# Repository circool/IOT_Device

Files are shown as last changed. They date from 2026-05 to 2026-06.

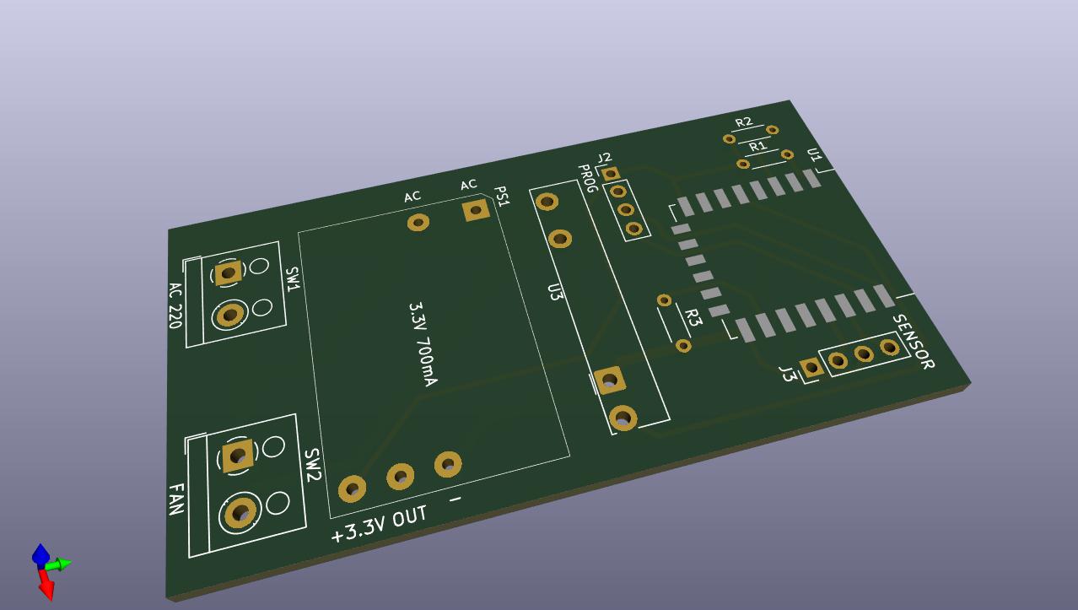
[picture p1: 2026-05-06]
Fan/Fan.jpg

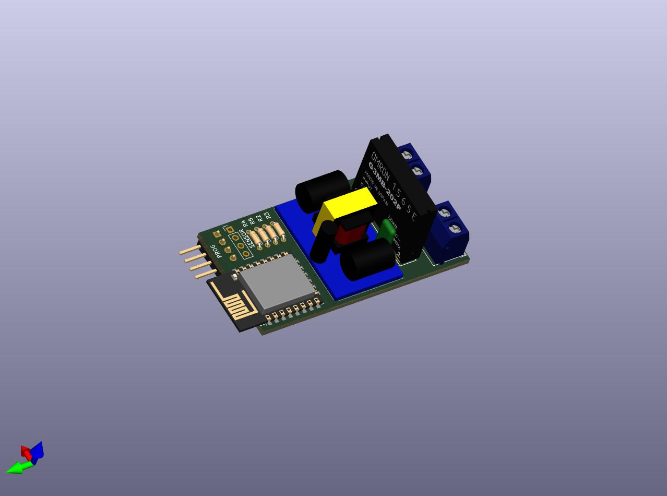
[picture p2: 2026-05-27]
Fan/Fan-review.jpg

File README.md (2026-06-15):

# Universal Smart Home Device







Универсальное устройство для умного дома с поддержкой датчиков температуры/влажности, ШИМ-управления вентилятором, MQTT и веб-интерфейсом. Идеально подходит для автоматизации вытяжной вентиляции в ванной и туалете.

## Особенности

- **Три типа устройств** в одной прошивке:
  - Вентилятор с датчиками (автоматическое управление)
  - Автономный датчик температуры/влажности
  - Управляемый выключатель

- **Smart-управление**:
  - Автоматическое включение по температуре/влажности
  - Ручное управление через MQTT и Web
  - Таймер отложенного включения
  - Аварийное отключение по таймеру

- **Тихий режим (ШИМ)**:
  - Регулировка скорости 0-100%
  - **Адаптивный режим** — автоматическая подстройка мощности
  - Стартовый импульс для надёжного запуска

- **Поддержка платформ**:
  - ESP8266 (NodeMCU, ESP-12F)
  - ESP32 (любые версии)

- **Датчики**:
  - AHT10 (I2C)
  - DHT11/DHT22 (1-Wire)

- **Связь и управление**:
  - MQTT с LWT и autodiscovery-ready топиками
  - Веб-интерфейс для настройки
  - OTA обновления прошивки
  - Точка доступа (AP) для первоначальной настройки
  - Сброс настроек кнопкой / MQTT / Web

- **Надёжность**:
  - Хранение настроек в EEPROM с CRC16
  - Watchdog Timer (WDT)
  - Автоматическое восстановление после потери связи

## Содержание

- [Поддерживаемые устройства](#-поддерживаемые-устройства)
- [Аппаратные требования](#-аппаратные-требования)
- [Схема подключения](#-схема-подключения)
- [Установка прошивки](#-установка-прошивки)
- [Конфигурация](#-конфигурация)
  - [Настройки в коде (config.h)](#-настройки-в-коде-configh)
  - [Настройки в среде (platformio.ini)](#-настройки-в-среде-platformioini)
  - [Файл credentials.h (опционально)](#-файл-credentialsh-опционально)
- [MQTT топики](#-mqtt-топики)
- [Логика работы](#-логика-работы)
- [Компиляция из исходников](#-компиляция-из-исходников)
- [TODO](#-todo)

## Поддерживаемые устройства

| Тип | DEVICE_TYPE | Компоненты | Применение |
|-----|---|---|---|
| **Вентилятор** | 1 | Датчик + ШИМ + реле | Вытяжка в ванной/туалете |
| **Датчик** | 2 | Только датчик | Мониторинг микроклимата |
| **Выключатель** | 3 | Реле (без датчика) | Управление освещением/нагрузкой |

## Аппаратные требования

### Компоненты (максимальная конфигурация)

| Компонент | Модель | Примечание |
|---|---|---|
| Микроконтроллер | ESP8266 (NodeMCU) или ESP32 | Любая плата с WiFi |
| Датчик (опционально) | AHT10 или DHT11/DHT22 | I2C или 1-Wire |
| Исполнительное реле | Твердотельное реле G3MB-202P | Для реализации ШИМ |
| Питание | AC-DC 220V → 3.3V | Подключается параллельно освещению |
| Кнопка сброса | Тактовая на замыкание | GPIO0 → GND |
| Светодиод индикации | Любой | С резистором 220-470 Ом (GPIO2* → GND, инверсия) |

### Назначение пинов

| Функция | ESP8266 | ESP32 |
|---|---|---|
| Управление (PWM) | GPIO14 | GPIO4 |
| AHT10 SDA | GPIO4 | GPIO21 |
| AHT10 SCL | GPIO5 | GPIO22 |
| DHT11/22 | GPIO4* | GPIO16* | Однопроводной датчик (GPIO → DATA) |
| Кнопка сброса | GPIO0 | GPIO0 |
| Светодиод индикации связи | GPIO2** | GPIO2** |

**Важно:** Для работы ШИМ-регулировки обязательно используйте **твердотельное реле (SSR)**, а не механическое!

**\*** DHT11/22 можно подключать к любым свободным пинам, кроме GPIO0, GPIO2, GPIO15 (ESP8266) из-за особого поведения при загрузке. Рекомендуемые пины: GPIO4, GPIO5, GPIO16 (ESP8266) или GPIO16, GPIO17, GPIO18 (ESP32).

**\*\*** На многих модулях NodeMCU и ESP32-devkit на GPIO2 уже установлен встроенный синий светодиод. При использовании DHT на GPIO2 возникнет конфликт — выберите другой пин для датчика или отключите LED.

## Схема подключения

```
220V AC →→→ AC-DC 3.3V →→→ ESP
           ↓
         Свет
           
220V AC →→→ SSR (реле) →→→ Вентилятор
           ↑
        GPIO (PWM)
           
ESP →→→ I2C →→→ AHT10 (SDA/SCL)
```

**Принцип работы:**
1. Свет включён → устройство получает питание
2. Устройство решает: включать вентилятор или нет (по датчикам)
3. Если нужно — подаёт ШИМ-сигнал на реле
4. Свет выключен → устройство обесточено → вентилятор выключен

## Установка прошивки

### Способ 1: PlatformIO (рекомендуется)

```bash
# Клонировать репозиторий
git clone https://github.com/circool/IOT_Device.git
cd IOT_Device

# Собрать для ESP8266
pio run -e esp8266 -t upload

# Или для ESP32
pio run -e esp32 -t upload
```

### Способ 2: Arduino IDE

1. Установите поддержку ESP8266/ESP32 через Boards Manager
2. Установите библиотеки:
   - PubSubClient by Nick O'Leary
   - Adafruit AHTX0
   - DHT sensor library
   - ElegantOTA
3. Откройте `main.cpp`, выберите плату и загрузите

### Первоначальная настройка

1. **Первый запуск** — устройство создаст точку доступа `Fan_XXXX` (или `Sensor_XXXX`/`Switch_XXXX`)
2. **Подключитесь** к этой WiFi сети (пароль отсутствует)
3. **Откройте браузер** по адресу `http://192.168.4.1`
4. **Заполните настройки:**
   - WiFi SSID и пароль
   - MQTT брокер (адрес и порт)
   - Параметры управления (при необходимости)
5. **Сохраните** — устройство перезагрузится и подключится к вашей сети

## Конфигурация

### Настройки в коде (config.h)

```cpp
// Тип устройства
#define DEVICE_TYPE 1  // 1=Fan, 2=Sensor, 3=Switch

// Датчик (для TYPE 1,2)
#define SENSOR_TYPE 1  // 1=AHT10, 2=DHT

// Аппаратные пины
#define SWITCH_PIN 4     // Пин управления (ESP32)
#define STATUS_LED_PIN 2 // LED индикации (0 = отключён)
#define RESET_PIN 0      // Кнопка сброса

// Функционал
#define WIFI_ENABLED 1
#define MQTT_ENABLED 1
#define WEB_STATUS_ENABLED 1
#define OTA_ENABLED 1
#define WDT_ENABLED 1

// Тайминги
#define WDT_TIMER_MS 5000           // Watchdog таймер
#define AP_FALLBACK_TIMEOUT_MS 12000 // Таймаут до перехода в AP

// ШИМ параметры (для TYPE 1)
#define PWM_FREQUENCY 5      // Частота ШИМ (Гц)
#define PWM_RESOLUTION 8     // Разрешение (бит)
#define PWM_STARTING 200     // Стартовый импульс (мс)
#define DEFAULT_SPEED_PERCENT 50 // Скорость по умолчанию (%)

// Адаптивный режим
#define ADAPTIVE_EPSILON_TEMP 0.5   // Чувствительность температуры
#define ADAPTIVE_EPSILON_HUM 2.0    // Чувствительность влажности
#define ADAPTIVE_STEP_SIZE 10       // Шаг адаптации (%)
#define MIN_SPEED_PERCENT 10        // Минимальная скорость при адаптации

// Пороги по умолчанию (для TYPE 1)
#define DEFAULT_LOW_TEMP 27.0
#define DEFAULT_HIGH_TEMP 29.0
#define DEFAULT_LOW_HUM 55.0
#define DEFAULT_HIGH_HUM 60.0
```

### Настройки в среде (platformio.ini)

Файл `platformio.ini` содержит все параметры сборки для разных платформ. Раздел разделён на общие настройки (`[common]`) и специфичные для каждой платформы (`[env:esp32]`, `[env:esp8266]`).

#### Структура файла

```ini
[common]                           # Общие настройки для всех платформ
framework = arduino                # Фреймворк
monitor_speed = 115200             # Скорость Serial порта
upload_speed = 460800              # Скорость загрузки прошивки
build_flags =                      # Флаги компиляции (общие)
    -DMAGIC_VALUE=0x5A6B          # Магическое число для EEPROM
    -DDEVICE_TYPE=1               # Тип устройства (1=Fan, 2=Sensor, 3=Switch)
    -DVERSION=\"1.4\"             # Версия прошивки
    -DSTATUS_LED_PIN=2            # Пин статусного LED (0=отключён)

[env:esp32]                        # Сборка для ESP32
platform = espressif32             # Платформа
board = esp32dev                   # Тип платы
extends = common                   # Наследование общих настроек
lib_deps = ...                     # Зависимости (библиотеки)
build_flags =                      # Специфичные флаги для ESP32
    ${common.build_flags}         # Включить общие флаги
    -DSWITCH_PIN=4                # Пин управления для ESP32
    -DLED_INVERTED=0              # Инверсия LED (0=нормальная логика)

[env:esp8266]                      # Сборка для ESP8266
platform = espressif8266           # Платформа
board = nodemcu                    # Тип платы
extends = common                   # Наследование общих настроек
build_flags = 
    ${common.build_flags}
    -DSWITCH_PIN=14               # Пин управления для ESP8266
    -DLED_INVERTED=1              # Инверсия LED (1=инвертированная)
board_build.flash_size = 4MB      # Размер flash памяти
board_build.flash_mode = dout     # Режим flash (для ESP8266)
```

#### Основные параметры сборки

| Параметр | Значение | Описание |
|---|---|---|
| `-DMAGIC_VALUE` | `0x5A6B` | Идентификатор корректной конфигурации в EEPROM |
| `-DDEVICE_TYPE` | `1`, `2`, `3` | Тип устройства (см. таблицу ниже) |
| `-DVERSION` | `"1.4"` | Версия прошивки (отображается в веб-интерфейсе) |
| `-DSTATUS_LED_PIN` | `2` | Пин для LED индикации (`0` = отключить) |
| `-DSWITCH_PIN` | `4` (ESP32) / `14` (ESP8266) | Пин управления реле/вентилятором |
| `-DLED_INVERTED` | `0` или `1` | Инверсия логики LED (`1` = HIGH выключает) |

#### Типы устройств (DEVICE_TYPE)

```ini
# Вентилятор с датчиками (полная функциональность)
-DDEVICE_TYPE=1

# Только датчик (без управления нагрузкой)
-DDEVICE_TYPE=2

# Управляемый выключатель (без датчика)
-DDEVICE_TYPE=3
```

#### Включение/отключение функционала

```ini
# Основные модули (по умолчанию ВСЕ включены)
-DWIFI_ENABLED=1          # WiFi поддержка
-DMQTT_ENABLED=1          # MQTT клиент
-DWEB_STATUS_ENABLED=1           # Веб-сервер
-DOTA_ENABLED=1           # OTA обновления
-DWDT_ENABLED=1           # Watchdog Timer

# Отключение ненужного функционала (экономия памяти)
; -DMQTT_ENABLED=0        # Пример отключения MQTT
; -DWIFI_ENABLED=0        # Полностью отключить WiFi
; -DWDT_ENABLED=0         # Отключить Watchdog (только для отладки)
```

#### Настройка отладки (логирование)

```ini
# Глобальное включение отладки
-DLOG_LEVEL=4

```

**Пример включения полной отладки:**
```ini
build_flags =
    ${common.build_flags}
    -DLOG_LEVEL=4
    
```

#### Настройка MQTT функционала

```ini
# MQTT возможности (требуют MQTT_ENABLED=1)
-DMQTT_RESET_ENABLED=1            # Разрешить сброс через MQTT
-DMQTT_PUBLISH_RSSI=1             # Публиковать RSSI WiFi
-DMQTT_PUBLISH_RESET_REASON=1     # Публиковать причину перезагрузки
-DMQTT_IGNORE_PUBLISH_NORMAL_RESET_REASONS=1  # Не публиковать штатные перезагрузки

# Настройки MQTT соединения
-DMQTT_RECONNECT_DELAY_MS=5000    # Задержка переподключения (мс)
-DMQTT_KEEPALIVE_SEC=3            # Keepalive интервал (сек)
```

#### Настройка веб-интерфейса

```ini
# WEB возможности (требуют WEB_STATUS_ENABLED=1)
-DWEB_STATUS_ENABLED=1            # Страница статуса
-DWEB_SHOW_RSSI=1                 # Отображать RSSI на странице
-DWEB_RESET_ENABLED=1             # Кнопка сброса в веб-интерфейсе

# Настройки точки доступа (AP)
-DAP_ENABLED=1                    # Включить режим AP
-DAP_FALLBACK_TIMEOUT_MS=12000    # Таймаут до перехода в AP (мс)
-DAP_IP_ADDRESS="192.168.4.1"     # IP адрес в режиме AP
```

#### Настройки Watchdog (WDT)

```ini
# Параметры Watchdog (требуют WDT_ENABLED=1)
-DWDT_TIMER_MS=5000               # Таймаут WDT (мс)
-DLOOP_WATCHDOG_MULTIPLIER=3      # Множитель для основного цикла
```

#### Настройки датчиков

```ini
# Тип датчика (для DEVICE_TYPE=1 или 2)
-DSENSOR_TYPE=1                   # 1 = AHT10 (I2C), 2 = DHT11/22 (GPIO)

# Параметры для DHT (если SENSOR_TYPE=2)
-DSENSOR_PIN=2                    # GPIO пин для DHT
-DDHT_TYPE=DHT11                  # Тип DHT (DHT11, DHT22, DHT21)

# Интервал опроса датчика (сек)
-DSENSOR_DURATION=10
```

#### Настройки ШИМ (для вентилятора)

```ini
# ШИМ параметры (для DEVICE_TYPE=1)
-DPWM_ENABLED=1                   # Включить ШИМ
-DPWM_FREQUENCY=5                 # Частота ШИМ (Гц) — 5 Гц оптимально для SSR
-DPWM_RESOLUTION=8                # Разрешение ШИМ (бит) — 8 бит = 0-255
-DPWM_STARTING=200                # Длительность стартового импульса (мс)

# Адаптивный режим (требует PWM_ENABLED=1)
-DAPAPTIVE_ENABLED=1              # Включить адаптивный режим
-DDEFAULT_SPEED_PERCENT=50        # Скорость по умолчанию (%)
-DMIN_SPEED_PERCENT=10            # Минимальная скорость при адаптации
-DADAPTIVE_EPSILON_TEMP=0.5       # Чувствительность температуры (°C)
-DADAPTIVE_EPSILON_HUM=2.0        # Чувствительность влажности (%)
-DADAPTIVE_STEP_SIZE=10           # Шаг изменения скорости (%)
-DADAPTIVE_SPEED_SENSITIVITY=0.7  # Чувствительность к скорости изменения
```

#### Настройки аварийной защиты

```ini
# Таймеры безопасности (для DEVICE_TYPE=1 или 3)
-DEMERGENCY_ENABLED=1             # Включить аварийное отключение
-DMAX_ON_TIME_SEC=3600            # Максимальное время работы (сек) — 1 час

# Таймер отложенного включения
-DDEFAULT_DELAY_SECONDS=60        # Задержка по умолчанию (сек)
-DBOOT_SWITCH_STATE=0             # Состояние при старте (0=выкл, 1=вкл)
```

#### Настройки WiFi

```ini
# Параметры WiFi (требуют WIFI_ENABLED=1)
-DWIFI_CONNECT_TIMEOUT_MS=30000   # Таймаут подключения (мс)

# Включить сканирование сетей при старте (только для отладки)
; -DSCANING_WIFI_ENABLED=1
```

#### Примеры готовых конфигураций

**1. Минимальная конфигурация (только датчик, без WiFi):**
```ini
[env:esp32]
build_flags =
    -DDEVICE_TYPE=2
    -DWIFI_ENABLED=0
    -DMQTT_ENABLED=0
    -DWEB_STATUS_ENABLED=0
    -DSENSOR_TYPE=1
    -DSTATUS_LED_PIN=0
```

**2. Полная конфигурация с отладкой:**
```ini
[env:esp32]
build_flags =
    ${common.build_flags}
    -DLOG_LEVEL=4
    
```

**3. Выключатель с таймером (без датчика):**
```ini
[env:esp8266]
build_flags =
    ${common.build_flags}
    -DDEVICE_TYPE=3
    -DSWITCH_PIN=14
    -DDEFAULT_DELAY_SECONDS=30
    -DMAX_ON_TIME_SEC=1800
    -DBOOT_SWITCH_STATE=0
```

**4. Тихий режим с адаптацией:**
```ini
[env:esp32]
build_flags =
    ${common.build_flags}
    -DDEVICE_TYPE=1
    -DPWM_ENABLED=1
    -DAPAPTIVE_ENABLED=1
    -DPWM_FREQUENCY=5
    -DDEFAULT_SPEED_PERCENT=70
    -DMIN_SPEED_PERCENT=20
    -DADAPTIVE_STEP_SIZE=5
```

#### Важные замечания

1. **Приоритет флагов:** Специфичные для платформы флаги переопределяют общие
2. **Экономия памяти:** Отключайте ненужный функционал (`MQTT_ENABLED=0`, `WEB_STATUS_ENABLED=0`) для ESP8266 (особенно важно при ограниченной flash)
3. **Частота ШИМ:** Для твердотельных реле оптимальна 5-10 Гц. Более высокая частота может вызвать перегрев реле
4. **ESP8266 нюансы:**
   - Требуется `-Wno-sign-compare` и `-Wno-uninitialized` для подавления предупреждений
   - Режим flash `dout` обязателен для некоторых плат
   - LED часто инвертирован (`LED_INVERTED=1`)

#### Изменение параметров без перекомпиляции

Некоторые параметры можно изменить через веб-интерфейс или MQTT без перепрошивки:
- Пороги температуры/влажности
- Скорость вентилятора
- Таймеры (задержка, аварийное отключение)
- Режимы работы (ручной/автоматический)

Параметры, требующие перекомпиляции:
- Тип устройства (`DEVICE_TYPE`)
- Назначение пинов (`SWITCH_PIN`, `STATUS_LED_PIN`)
- Частота ШИМ (`PWM_FREQUENCY`)
- Включение/отключение модулей (`MQTT_ENABLED`, `WEB_STATUS_ENABLED`)
```

### Файл credentials.h (опционально)

Создайте этот файл для заводских настроек:

```cpp
// credentials.h
#define SSID_NAME "MyWiFi"
#define WIFI_PASSWORD "MyPassword"
#define MQTT_ADDRESS "192.168.1.100"
#define MQTT_PORT 1883
#define MQTT_USER "user"
#define MQTT_PASSWORD "pass"
```

## MQTT топики

Устройство использует префикс вида `{Type}_{ID}` (например `Fan_D84C`).

### Общие топики

| Топик | Направление | Формат | Описание |
|---|---|---|---|
| `{prefix}/status` | Dev → Broker | `Online`/`Offline` | Статус (LWT) |
| `{prefix}/version` | Dev → Broker | `1.4` | Версия прошивки |
| `{prefix}/c/system/reset` | Broker → Dev | `1` | Сброс настроек |

### Для вентилятора (TYPE 1)

| Топик | Направление | Описание |
|---|---|---|
| `{prefix}/fan/state` | Dev → Broker | `ON`/`OFF` |
| `{prefix}/c/fan/state` | Broker → Dev | Управление |
| `{prefix}/fan/speed` | Dev → Broker | Скорость (0-100%) |
| `{prefix}/c/fan/speed` | Broker → Dev | Установка скорости |
| `{prefix}/fan/adaptiveMode` | Dev → Broker | Адаптивный режим |
| `{prefix}/fan/delaySec` | Dev → Broker | Задержка включения |
| `{prefix}/fan/maxOnTime` | Dev → Broker | Аварийное отключение |
| `{prefix}/fan/sensorControlMode` | Dev → Broker | Режим датчика |
| `{prefix}/sensor/temperature` | Dev → Broker | Температура |
| `{prefix}/sensor/humidity` | Dev → Broker | Влажность |
| `{prefix}/sensor/lowTemp` | Dev → Broker | Нижний порог T |
| `{prefix}/c/sensor/highTemp` | Broker → Dev | Верхний порог T |

### Для датчика (TYPE 2)

| Топик | Направление | Описание |
|---|---|---|
| `{prefix}/sensor/temperature` | Dev → Broker | Температура |
| `{prefix}/sensor/humidity` | Dev → Broker | Влажность |

### Для выключателя (TYPE 3)

| Топик | Направление | Описание |
|---|---|---|
| `{prefix}/switch/state` | Dev → Broker | Состояние |
| `{prefix}/c/switch/state` | Broker → Dev | Управление |
| `{prefix}/switch/delaySec` | Dev → Broker | Задержка включения |
| `{prefix}/switch/maxOnTime` | Dev → Broker | Аварийное отключение |

## Логика работы

### Режимы работы

1. **Режим датчика** (`sensorControlMode = 1`):
   - Включение: температура ≥ `highTemp` **ИЛИ** влажность ≥ `highHum`
   - Выключение: температура ≤ `lowTemp` **И** влажность ≤ `lowHum`

2. **Ручной режим** (`sensorControlMode = 0`):
   - Игнорирует датчик
   - Управление только через MQTT/Web

3. **Адаптивный режим** (при `speedPercent < 100`):
   - Автоматически повышает/понижает скорость
   - Старается удержать температуру/влажность на уровне момента включения

### Таймеры

- **Отложенное включение** (`delaySeconds`):
  - Запускается при выключении вентилятора
  - По истечении — принудительное включение

- **Аварийное отключение** (`maxOnTime`):
  - Защита от перегрева
  - По истечении — выключение + переход в ручной режим

### Приоритеты команд

1. **Ручное управление** (MQTT/Web) — наивысший приоритет
2. **Таймер отложенного включения**
3. **Режим управления датчиком**

## Компиляция из исходников

### Структура проекта

```
├── main.cpp           # Основной цикл
├── config.h/cpp       # Настройки и EEPROM
├── mqtt.h/cpp         # MQTT клиент
├── web.h/cpp          # Веб-сервер
├── sensor.h/cpp       # Датчики
├── fan.h/cpp          # Управление вентилятором
├── switch.h/cpp       # Управление выключателем
├── led.h/cpp          # LED индикация
├── ansi.h             # Цветной вывод в Serial
├── web_strings.h      # HTML строки
└── platformio.ini     # Конфигурация сборки
```

### PlatformIO конфигурация

```ini
[env:esp32]
platform = espressif32
board = esp32dev
build_flags = 
    -DDEVICE_TYPE=1
    -DMQTT_ENABLED=1
    -DWEB_STATUS_ENABLED=1
lib_deps = 
    knolleary/PubSubClient @ ^2.8
    adafruit/Adafruit AHTX0 @ ^2.0.5
    ayushsharma82/ElegantOTA @ ^2.2.8
    adafruit/DHT sensor library@^1.4.6
```

### Предупреждение относительно OTA

**ESP8266 с 1MB flash (ESP-01, ESP-07) не поддерживают OTA!**
Несмотря на то, что веб-интерфейс ElegantOTA показывает успешную загрузку, после перезагрузки устройство останется на старой прошивке. Для OTA требуется минимум **2MB flash**. Используйте модули с 4MB (NodeMCU, Wemos D1 mini, ESP-12F) или установите константу/флаг `OTA_ENABLED=0` / `-DOTA_ENABLED=0` для исключения OTA.

### Отладка

```cpp
// В platformio.ini
build_flags = 
    -DLOG_LEVEL=4                 // Логи Web
```

## TODO

- [ ] Реализовать MQTT Discovery для Home Assistant
- [ ] Добавить поддержку ESP32-C6 (ZigBee/Matter)

---

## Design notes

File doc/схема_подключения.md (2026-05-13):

# Схема подключения

## ESP32

### ESP32-WROOM-32
2x15 pin

### Датчик (AHT10)

			 ------------
			 |			|				------------------------|
VDD x--------| xxxxxxx	|				|						|
			 |			|---------------|						|
SDA x--------| xxxxxxx								CHIP		|
 			 |			|---------------|						|
GND x--------| xxxxxxx	|				|						|
 			 |			|				------------------------|
SCL x--------| xxxxxxx	|
			 ------------

VDD 	-> 	VCC
SDA 	->	D21 ( GPIO1 IC2_SDA)
GND 	->  GND
SCL		->  D22 ( GPIO22 IC2_SCL )

## 8266

### ESP-12E

2x8 pin

		 	 |----------------|
		 	 |      -ANTENA-  |
		 	 |			      |
		 	 |			      |
	RST   	x| |------------| | x TXD0
	ADC		x| |            | | x RXD0
	EN		x| |            | | x GPIO5
	GPIO16	x| | ESP8266MOD | | x GPIO4
	GPIO14	x| |            | | x GPIO0
	GPIO12	x| |            | | x GPIO2
	GPIO13	x| |            | | x GPIO15
	VCC		x| |------------| | x GND
		 	 |________________|

### Обвязка для программирования 

RST 	- 10K 		- VCC
GPIO15	- 10K		- GND
EN 		- 10K 		- VCC

### Подключение для программирования

RX0 
TX0
VCC
GND

### Выключатель (модуль Solid State Relay Low Level Trigger) на G3MB=-202P 1565E (5 VDC)

DC+ 	-> 	VCC
DC- 	->	GND
CH1 	->  GPI14

### Датчик (AHT10)

			 ------------
			 |			|				------------------------|
VDD x--------| xxxxxxx	|				|						|
			 |			|---------------|						|
SDA x--------| xxxxxxx								CHIP		|
 			 |			|---------------|						|
GND x--------| xxxxxxx	|				|						|
 			 |			|				------------------------|
SCL x--------| xxxxxxx	|
			 ------------

VDD 	-> 	VCC
SDA 	->	GPIO4 GPIO1 IC2_SDA - зеленый
GND 	->  GND
SCL		->  GPIO5 IC2_SCL

Питание устройства миниатюрный модуль 220 -> 3.3 V

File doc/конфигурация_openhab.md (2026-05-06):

# Пример конфигурации для  Openhab

```
MQTT_ADDRESS
MQTT_USER
MQTT_PASSWORD
```

## Things
#### mqtt.things
Bridge mqtt:broker:local [ 
  host=MQTT_ADDRESS, 
  secure=false, 
  username=MQTT_USER, 
  password=MQTT_PASSWORD
] {

Thing ...

```
Thing topic fan_esp32 "Вентилятор esp32" [ availabilityTopic="C0:49:EF:6B:D8:4C/status", payloadAvailable="Online", payloadNotAvailable="Offline" ] {

      Type switch : state "Состояние" [
        stateTopic="C0:49:EF:6B:D8:4C/status", on="Online", off="Offline"
      ]

      Type switch : fan "Вентилятор" [
        stateTopic="C0:49:EF:6B:D8:4C/switch/state" , on="ON", off="OFF",
        commandTopic="C0:49:EF:6B:D8:4C/switch/c", on="1", off="0"
      ]

      Type number : humidity "Влажность" [
        stateTopic="C0:49:EF:6B:D8:4C/sensor/humidity"
      ]
      
      Type number : lohum "Low Hummidity Range" [
        stateTopic="C0:49:EF:6B:D8:4C/sensor/lowHum",
        commandTopic="C0:49:EF:6B:D8:4C/sensor/c/lowHum",
        min=0,
        max=100,
        unit="%"
      ]

      Type number : hihum "High Humidity Range" [
        stateTopic="C0:49:EF:6B:D8:4C/sensor/highHum",
        commandTopic="C0:49:EF:6B:D8:4C/sensor/c/highHum",
        min=0,
        max=100,
        unit="%"
      ]

      Type number : temperature  "Температура" [
        stateTopic="C0:49:EF:6B:D8:4C/sensor/temperature"
      ]

      Type number : lotemp  "Low Temperature Range" [
        stateTopic="C0:49:EF:6B:D8:4C/sensor/lowTemp",
        commandTopic="C0:49:EF:6B:D8:4C/sensor/c/lowTemp",
        unit="°C",
        min=-50,
        max=50
      ]

      Type number : hitemp  "High Temperature Range" [
        stateTopic="C0:49:EF:6B:D8:4C/sensor/highTemp",
        commandTopic="C0:49:EF:6B:D8:4C/sensor/c/highTemp",
        unit="°C",
        min=-50,
        max=50
      ] 

      Type number : delay  "Fan delay" [
        stateTopic="C0:49:EF:6B:D8:4C/sensor/fanDelay",
        commandTopic="C0:49:EF:6B:D8:4C/sensor/c/fanDelay",
        unit="sec",
        min=0
      ]
  }
```
  
  }

  ## Items

  ### fans.items

```
  Group   gFan32 "Вентилятор ESP-32"    <fan> (loc_Cabinet,g_Sensors) ["Fan"]

Switch fan_esp32_state "Статус подключения" <f7:antenna_radiowaves_left_right> 	(gFan32) ["Status"] {
	channel="mqtt:topic:local:fan_esp32:state", on="Online", off="Offline"
}

Switch fan_esp32_fan "Вытяжка" <oh:switch>	(gFan32,loc_Cabinet) ["Fan","Switch"]  {
	channel="mqtt:topic:local:fan_esp32:fan"
}

Number:Dimensionless fan_esp32_humidity "Влажность  [%d]" <humidity> (gFan32,loc_Cabinet,gHumidities)      
	["Measurement","Humidity"] 
		{ channel="mqtt:topic:local:fan_esp32:humidity" }

Number:Temperature fan_esp32_temperature "Температура [%.2f °C]" <temperature> (gFan32,loc_Cabinet,gTemperatures) ["Measurement","Temperature"] {
        channel="mqtt:topic:local:fan_esp32:temperature"
}

Number  fan_esp32_lohum "Low Humidity range [%.2f %]" <humidity> (gFan32,loc_Cabinet)      ["Fan","Setpoint"] {
        channel="mqtt:topic:local:fan_esp32:lohum"

}

Number  fan_esp32_hihum "High Humidity range [%.2f %]" <humidity> (gFan32,loc_Cabinet)      ["Fan","Setpoint"] {
        channel="mqtt:topic:local:fan_esp32:hihum"

}

Number  fan_esp32_lotemp "Low Temperature range [%.2f °C]" <temperature_cold> (gFan32,loc_Cabinet)      ["Fan","Setpoint"] {
        channel="mqtt:topic:local:fan_esp32:lotemp"

}

Number  fan_esp32_hitemp "High Temperature range [%.2f °C]" <temperature_hot> (gFan32,loc_Cabinet)      ["Fan","Setpoint"] {
        channel="mqtt:topic:local:fan_esp32:hitemp"

}

Number 	fan_esp32_delay "Fan delay [%d sec]" <clock> (gFan32,loc_Cabinet)      ["Fan","Setpoint"] {
        channel="mqtt:topic:local:fan_esp32:delay"

}
```

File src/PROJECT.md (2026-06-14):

# Универсальное устройство умного дома

## Описание проекта

### Цель создания

Устройство разработано для автоматического управления вытяжной вентиляцией в туалете и ванной комнате. В типовой квартирной разводке вытяжной вентилятор подключён к цепи освещения и включается одновременно со светом, работая всё время пока в помещении горит свет — без учёта реальной потребности в вентиляции. Устройство решает эту проблему: вентилятор включается автоматически только при превышении порогов температуры или влажности, а не при каждом использовании помещения.

## Основные возможности и режимы работы

Прошивка устройства универсальна и на этапе компиляции настраивается на один из трёх типов:

| Тип | Назначение | Ключевые компоненты |
|-----|---|---|
| 1 | Вентилятор с датчиком | Датчик температуры/влажности + реле |
| 2 | Автономный датчик | Только датчик температуры/влажности |
| 3 | Управляемый выключатель | Реле, без датчика |

Каждый тип поддерживает различные каналы взаимодействия и набор функций, описанных ниже.

---

### Описание режимов работы и функциональных особенностей

#### Общие для всех типов возможности

**Хранение настроек.** Все параметры конфигурации сохраняются в энергонезависимой памяти устройства и не теряются при отключении питания.

**Светодиодная индикация.** Встроенный светодиод отображает текущий статус: наличие соединения с WiFi и MQTT, режим настройки, аварийное отключение исполнительного механизма.

**Режим настройки (точка доступа).** При первом включении или потере связи с настроенной сетью устройство автоматически создаёт собственную WiFi-сеть. Подключившись к ней, пользователь получает доступ к веб-интерфейсу для ввода параметров WiFi и MQTT.

**Каналы взаимодействия:**
- WiFi — транспорт для MQTT и веб-интерфейса
- TODO: Zigbee/Matter
- TODO: Служба автоматического обнаружения для экосистем умного дома

**Сброс настроек.** Предусмотрена возможность принудительного сброса всех параметров к значениям по умолчанию — по команде через канал взаимодействия или длительным нажатием аппаратной кнопки сброса.

**Обновление прошивки.** Поддерживается обновление «по воздуху» (OTA) через веб-интерфейс, без демонтажа устройства.

**Программный Watch Dog.** Аппаратный сторожевой таймер отслеживает зависания устройства и выполняет автоматическую перезагрузку.

---

#### Для типов 1 и 3 (исполнительное устройство)

**Таймер аварийного отключения.** Принудительно отключает нагрузку, если она проработала непрерывно дольше заданного времени. Служит защитным механизмом, предотвращая бесконечную работу. Настраивается **только при конфигурации устройства**, может быть отключён установкой нулевого значения.

**Начальное состояние при старте.** Определяет поведение реле сразу после подачи питания: включено или выключено. Настраивается **только при конфигурации устройства**.

---

#### Для типа 1 (вентилятор, управляемый датчиком)

Устройство типа 1 поддерживает несколько режимов управления исполнительным механизмом. Режимы выстроены по приоритету: **Ручной режим → Режим управления сенсором/таймером**.

**Ручной режим (наивысший приоритет).** Включается немедленно после получения прямой команды пользователя по любому из каналов взаимодействия (MQTT или веб-интерфейс). В этом режиме показания датчика и таймер отложенного включения игнорируются. Таймер аварийного отключения продолжает работать. Данные датчиков продолжают публиковаться. Режим действует до явной команды возврата в режим управления сенсором или до перезагрузки устройства.

**Режим управления сенсором.** Основной автоматический режим. Исполнительный механизм включается при превышении хотя бы одного из верхних порогов: температуры **или** влажности. Выключение происходит только при одновременном снижении **обоих** показателей ниже нижних порогов. Пороги задаются при конфигурации устройства, но могут быть изменены пользователем оперативно (изменения действуют до выключения устройства).

**Режим управления таймером.** Предназначен для ситуаций, когда показания датчика малоинформативны (например, длительное использование туалета без значительных изменений влажности). Исполнительный механизм включается по прошествии заданного периода после подачи питания. Настраивается **только при конфигурации устройства**, может быть отключён установкой нулевого значения.

**Дополнительные возможности для типа 1:**

**Тихий режим (Slow Mode).** Снижает шум вентилятора за счёт импульсной подачи питания (ШИМ) с настраиваемой скважностью 0–100%. Может быть активирован при конфигурации устройства. Пользователь может оперативно включать/выключать этот режим и изменять скважность (изменения действуют до выключения устройства).

**Адаптивный тихий режим.** Работает только при активном тихом режиме. Автоматически увеличивает мощность вентилятора при ухудшении показателей окружающей среды (рост температуры или влажности), чтобы ускорить нормализацию микроклимата. Алгоритм адаптации задаётся жёстко при компиляции. Активируется при конфигурации устройства, пользователь может отключить адаптацию оперативно (изменения действуют до выключения устройства).

---

#### Для типа 2 (автономный датчик)

Устройство выполняет единственную функцию — периодический опрос датчика температуры и влажности и публикацию показаний по доступным каналам взаимодействия. Режимы управления исполнительным механизмом отсутствуют.

---

#### Для типа 3 (управляемый выключатель)

Устройство управляется только прямыми командами пользователя через каналы взаимодействия (ручной режим). Датчик отсутствует, режим управления сенсором и адаптивный тихий режим не применимы.

Доступные функции:
- **Режим управления таймером** — включение по прошествии заданного периода после подачи питания.
- **Таймер аварийного отключения** — принудительное отключение при превышении времени непрерывной работы.

---

## Технические описания и пояснения логики работы

### Логика работы

Устройство работает в двух режимах: **режим настройки** и **обычный режим**.

#### Первый запуск

При включении устройство пытается прочитать конфигурацию из энергонезависимой памяти:
- если параметры корректны — переход в **обычный режим**;
- если параметры отсутствуют или повреждены — переход в **режим настройки**.

#### Режим настройки

1. Используются значения по умолчанию из `credentials.h`.
2. Запускается точка доступа (AP) с идентификатором вида `{fan|sensor|switch}_XXXX`, где `XXXX` — последние 4 символа MAC-адреса. Эта-же строка используется как `prefix` для MQTT-топиков.
3. Запускается веб-сервер на `192.168.4.1` со страницей настройки.
4. Пользователь вводит (при необходимости изменяет) параметры WiFi и MQTT и сохраняет их.
5. После сохранения устройство перезагружается и переходит в **обычный режим**.

Перед сохранением введённых пользователем настроек производится их валидация. В режиме настройки опрос датчиков и управление исполнительным механизмом не производятся.

#### Обычный режим

1. Чтение конфигурации из энергонезависимой памяти.
2. Инициализация датчика (если предусмотрен типом устройства).
3. Инициализация пина управления исполнительным механизмом (если предусмотрен).
4. Запуск основной логики, **не дожидаясь** подключения к каналам взаимодействия:
   - периодический опрос датчика;
   - управление исполнительным механизмом согласно приоритету режимов;
   - контроль таймера аварийного отключения;
   - обслуживание веб-сервера.
5. Подключение к WiFi-сети по сохранённым параметрам.
6. При невозможности подключения в течение заданного тайм-аута — переход в **режим настройки**.
7. Подключение к MQTT-брокеру, публикация статуса `Online`.
8. При потере соединения — автоматические попытки переподключения.

---

### Описание режимов и терминов

**Ручной режим.** Активируется внешней командой по каналам взаимодействия. Блокирует управление от датчика и таймера. Возврат — командой `sensorControlMode` или перезагрузкой.

**Режим управления таймером.** Включение нагрузки по истечении `delaySeconds` после подачи питания. Работает **параллельно** с режимом управления сенсором (если включен): таймер может включить вентилятор независимо от показаний датчика, однако срабатывание таймера переводит управление в ручной режим, игнорирующий показания сенсора. Отключается командой ручного управления.

**Состояние исполнительного механизма при старте.** Параметр, определяющий положение реле сразу после подачи питания: включено/выключено. Настраивается при конфигурации.

**Тихий режим (Slow Mode).** ШИМ-управление с настраиваемой скважностью 0–100%. Стартовый импульс на полной мощности обеспечивает надёжный пуск вентилятора. Значения ниже минимального порога интерпретируются как команда выключения.

**Адаптивный тихий режим.** При активном тихом режиме отслеживает изменение показателей среды и динамически увеличивает скважность. При ошибке датчика переключает вентилятор на полную мощность. Ручное изменение скважности отключает адаптацию.

**Сохранение и отображение настроек.** Постоянные параметры сохраняются только через веб-форму конфигурации. Оперативные изменения действуют до перезагрузки и не сохраняются в энергонезависимой памяти.

**Принудительный сброс настроек.** Выполняется длительным нажатием кнопки сброса, командой MQTT или через веб-интерфейс. Устройство перезагружается в режим настройки.

**Программный Watch Dog.** Аппаратный таймер, перезагружающий устройство при зависании.

**Отображение причины перезагрузки.** При перезагрузке по ошибке причина публикуется в MQTT-топик `{prefix}/last_reset`. Штатные перезагрузки не публикуются.

**Индикация состояния соединений.** Светодиод отображает факт срабатывания таймера аварийного отключения, режим точки доступа, текущий статус подключения к WiFi и MQTT: постоянное свечение — работа в штатном режиме, серии вспышек — нештатное состояние.

## Техническая информация

### Индикация состояния соединений

Устройство использует светодиод для отображения текущего статуса подключения. Индикация работает, если в конфигурации задан пин светодиода (`STATUS_LED_PIN`). При значении `0` функция отключена.
Для отладки удобно использовать имеющийся на мекетных платах синий светодиод (на 2 пине). 
Для нестандартного подключения редусмотрена возможность инверсии логики (константа `LED_INVERTED`)

| Состояние | Сигнал светодиода |
|---|---|
| Подключение к WiFi и MQTT установлено | Постоянное свечение |
| Потеря соединения с WiFi | Одиночные вспышки с интервалом 1 сек |
| Потеря соединения с MQTT (WiFi активен) | Двойные вспышки с интервалом 1 сек |
| Режим настройки (точка доступа) | Тройные вспышки с интервалом 1 сек |
| Аварийное отключение исполнительного механизма | вспышки длиной 1 сек интервалом 2 сек |

Индикация позволяет быстро диагностировать состояние устройства без доступа к веб-интерфейсу или MQTT.

### Каналы взаимодействия — описание и особенности

#### MQTT

MQTT — основной протокол интеграции устройства в экосистемы умного дома. Устройство подключается к заданному брокеру, публикует своё состояние и принимает команды управления.

**Принцип формирования топиков**

Все топики строятся по схеме: `{prefix}/{группа}/{параметр}`

Префикс (`prefix`) формируется при первом запуске на основе типа устройства и последних четырёх символов MAC-адреса:
- `fan_XXXX` — для типа 1 (вентилятор с датчиком)
- `sensor_XXXX` — для типа 2 (автономный датчик)
- `switch_XXXX` — для типа 3 (управляемый выключатель)

Топики управления (команды от брокера к устройству) формируются добавлением `c/` в путь: `{prefix}/c/{группа}/{параметр}`

---

**Топики только для публикации (устройство → брокер)**

Устройство публикует значения, управление извне не предусмотрено.

| Топик | Описание | Применимость |
|---|---|---|
| `{prefix}/status` | Статус устройства: `Online` / `Offline` (LWT) | Все типы |
| `{prefix}/sensor/temperature` | Текущая температура | Типы 1, 2 |
| `{prefix}/sensor/humidity` | Текущая влажность | Типы 1, 2 |
| `{prefix}/last_reset` | Причина последней перезагрузки | Все типы  |
| `{prefix}/version` | Версия прошивки | Все типы |
| `{prefix}/rssi` | Сила сигнала WiFi | Все типы |

---

**Топики только для управления (брокер → устройство)**

Устройство принимает команды, но не публикует текущее значение параметра.

| Топик | Описание | Применимость |
|---|---|---|
| `{prefix}/c/system/reset` | Сброс настроек к значениям по умолчанию | Все типы |

---

**Двунаправленные топики (публикация и управление)**

Устройство публикует текущее значение параметра и принимает команды на его изменение.

*Исполнительное устройство (типы 1, 3):*

| Топик | Описание | Применимость |
|---|---|---|
| `{prefix}/fan/state` | Состояние исполнительного механизма | Типы 1, 3 |
| `{prefix}/fan/delaySec` | Задержка отложенного включения | Типы 1, 3 |
| `{prefix}/fan/maxOnTime` | Время аварийного отключения | Типы 1, 3 |

**Примечание:** для типа 3 (выключатель) в топиках используется `switch` вместо `fan`.

*Режимы работы (только тип 1):*

| Топик | Описание |
|---|---|
| `{prefix}/fan/sensorControlMode` | Режим управления сенсором |
| `{prefix}/fan/adaptiveMode` | Адаптивный тихий режим |
| `{prefix}/fan/speed` | Текущая скважность ШИМ |

*Пороги датчика (только тип 1):*

| Топик | Описание |
|---|---|
| `{prefix}/sensor/lowTemp` | Нижний порог температуры |
| `{prefix}/sensor/highTemp` | Верхний порог температуры |
| `{prefix}/sensor/lowHum` | Нижний порог влажности |
| `{prefix}/sensor/highHum` | Верхний порог влажности |

---

**Особенности взаимодействия:**
- Прямая команда управления состоянием автоматически переводит устройство в ручной режим.
- Все команды имеют оперативный характер — действуют до перезагрузки устройства.
- Сохранение параметров в энергонезависимую память производится **только** через веб-интерфейс.
- При выключении исполнительного механизма скважность ШИМ восстанавливается до сохранённого значения.
- При ручном изменении скважности адаптивный режим автоматически отключается.

### Режимы отладки и логирования

#### Уровни логирования

Уровень логирования задаётся макросом `LOG_LEVEL` в `config.h` или через `build_flags` в `platformio.ini`:

| Значение | Уровень | Описание |
|---|---|---|
| 0 | NONE | Логирование отключено полностью |
| 1 | ERROR | Только критические ошибки |
| 2 | WARN | Предупреждения + ERROR |
| 3 | INFO | Основные события (подключение, переключение режимов) + WARN + ERROR |
| 4 | DEBUG | Все сообщения, включая отладочные (по умолчанию) |

**Пример установки в `platformio.ini`:**
```ini
build_flags =
    -DLOG_LEVEL=3    ; INFO уровень
```

#### Категории логирования

Категории позволяют фильтровать сообщения по модулям. Значение `LOG_CATEGORIES` — битовая маска.

| Категория | Бит | Значение | Описание |
|---|-----|---|---|
| CAT_CONFIG | 1 << 0 | 1 | Конфигурация и EEPROM |
| CAT_SENSOR | 1 << 1 | 2 | Датчик температуры/влажности |
| CAT_FAN | 1 << 2 | 4 | Вентилятор (управление, ШИМ) |
| CAT_SWITCH | 1 << 3 | 8 | Выключатель |
| CAT_ACTUATOR | 1 << 4 | 16 | Базовый класс исполнительного механизма |
| CAT_MQTT | 1 << 5 | 32 | MQTT-клиент (подключение, публикации) |
| CAT_WIFI | 1 << 6 | 64 | WiFi (подключение, AP режим) |
| CAT_WEB | 1 << 7 | 128 | Web-сервер |
| CAT_OTA | 1 << 8 | 256 | OTA обновления |
| CAT_LED | 1 << 9 | 512 | Светодиодная индикация |
| CAT_WDT | 1 << 10 | 1024 | Watchdog таймер |
| CAT_AP | 1 << 11 | 2048 | Режим точки доступа |
| CAT_MAIN | 1 << 12 | 4096 | Основной цикл и инициализация |

**Комбинации категорий:**

| Значение | Включённые категории |
|---|---|
| `0xFFFF` | Все категории (по умолчанию) |
| `0x0001` | Только CAT_CONFIG |
| `0x0060` | CAT_MQTT + CAT_WIFI (32+64) |
| `0x0FFF` | Все категории, кроме CAT_MAIN |

**Пример включения только WiFi и MQTT логов:**
```ini
build_flags =
    -DLOG_CATEGORIES=0x0060
```

#### Цветной вывод

Цветной вывод логов в терминал включён по умолчанию (`LOG_USE_COLOR = 1`). Уровни имеют следующие цвета:

| Уровень | Цвет |
|---|---|
| ERROR | Ярко-красный |
| WARN | Ярко-пурпурный |
| INFO | Стандартный (сброс) |
| DEBUG | Синий |

**Отключение цветов:**
```ini
build_flags =
    -DLOG_USE_COLOR=0
```

#### Примеры настройки в `platformio.ini`

```ini
[common]
build_flags =
    ; Только ошибки и предупреждения, без отладочных сообщений
    -DLOG_LEVEL=2
    
    ; Только MQTT и WiFi логи
    -DLOG_CATEGORIES=0x0060
    
    ; Монохромный вывод (без ANSI-цветов)
    -DLOG_USE_COLOR=0
```

#### Логирование в коде

Для добавления логов в прошивку используются макросы:

```cpp
LOG_ERROR(CAT_MODULE, "Ошибка: %s", reason);
LOG_WARN(CAT_MODULE, "Предупреждение: %d", value);
LOG_INFO(CAT_MODULE, "Событие выполнено");
LOG_DEBUG(CAT_MODULE, "Отладочная информация: %.2f", data);
```

Где `CAT_MODULE` — одна из категорий из таблицы выше.

#### Особенности

- Логи выводятся в последовательный порт (`Serial`) со скоростью `MONITOR_SPEED` (по умолчанию 115200)
- При включённом цветном выводе логгер автоматически сбрасывает цвет перед каждой строкой для корректного отображения в терминалах
- Сообщения длиннее 256 символов обрезаются
- При уровне `LOG_LEVEL_NONE (0)` все макросы логирования превращаются в пустые операции, не потребляя ресурсы

#### TODO: Zigbee (переосмыслить)

Zigbee — протокол для построения ячеистых сетей с низким энергопотреблением. Устройство подключается к координатору сети (например, Zigbee-шлюзу) и представляет себя как одно или несколько логических устройств (endpoints) со стандартизированными кластерами.

**Принцип адресации**

Устройство идентифицируется в сети по 16-битному сетевому адресу и 64-битному MAC-адресу. Взаимодействие строится по модели:
`{endpoint} → {cluster} → {attribute}`

**Конечные точки (Endpoints)**

Устройство представляет три конечные точки в зависимости от конфигурации типа:

| Endpoint | Назначение | Применимость |
|---|---|---|
| 1 | Управление вентилятором | Типы 1, 3 |
| 2 | Датчик температуры и влажности | Типы 1, 2 |
| 3 | Конфигурация устройства | Все типы |

**Кластеры и атрибуты**

*Endpoint 1 — Управление вентилятором (типы 1, 3):*

| Кластер | Тип | Атрибуты |
|---|-----|---|
| On/Off (0x0006) | Сервер | `OnOff` — состояние исполнительного механизма |
| Level Control (0x0008) | Сервер | `CurrentLevel` — скважность ШИМ (0–100%) |
| Fan Control (0x0202) | Сервер | `FanMode` — режим работы (ручной/сенсор); `FanModeSequence` — адаптивный режим |

*Endpoint 2 — Датчик (типы 1, 2):*

| Кластер | Тип | Атрибуты |
|---|-----|---|
| Temperature Measurement (0x0402) | Сервер | `MeasuredValue` — текущая температура |
| Relative Humidity Measurement (0x0405) | Сервер | `MeasuredValue` — текущая влажность |

*Endpoint 3 — Конфигурация (все типы):*

| Кластер | Тип | Атрибуты |
|---|-----|---|
| Basic (0x0000) | Сервер | `ManufacturerName`, `ModelIdentifier`, `SWBuildID` — информация об устройстве и версии прошивки |
| OTA Upgrade (0x0019) | Клиент | Обновление прошивки по воздуху |
| Custom (0xFC00) | Сервер | Пороги датчика (`LowTemp`, `HighTemp`, `LowHum`, `HighHum`); таймеры (`DelaySeconds`, `MaxOnTime`); причина перезагрузки |

**Типы взаимодействия**

| Кластер | Публикация | Управление |
|---|---|---|
| On/Off | Да. Состояние сообщается через `Report Attributes` | Да. Команды `On`, `Off`, `Toggle` |
| Level Control | Да. Текущий уровень | Да. Команда `MoveToLevel` |
| Fan Control | Да. Текущий режим | Да. Команда `Write Attributes` |
| Temperature Measurement | Да. Периодические отчёты | Нет |
| Relative Humidity Measurement | Да. Периодические отчёты | Нет |
| Basic | Да. Статические атрибуты | Нет |
| OTA Upgrade | Нет | Да. Приём обновлений |
| Custom | Да. Текущие значения | Да. `Write Attributes` для порогов и таймеров |

**Особенности:**
- Обмен данными происходит через механизм биндингов (прямые связи между устройствами) или через координатор.
- Периодичность отчётов датчиков настраивается через конфигурацию кластеров.
- При потере и восстановлении связи устройство автоматически перерегистрируется в сети.

#### TODO: Matter (переосмыслить)

Matter — современный протокол умного дома, работающий поверх IP (WiFi, Thread). Обеспечивает унифицированное представление устройства и взаимодействие с экосистемами разных производителей.

**Принцип представления**

Устройство представляется как единый Matter-узел (Node), содержащий несколько конечных точек (Endpoints) с типами устройств и кластерами, описанными в спецификации Matter. Взаимодействие строится по модели:
`{Node ID} → {Endpoint} → {Cluster} → {Attribute}`

**Типы устройств (Device Types)**

Каждая конечная точка соответствует стандартизированному типу устройства:

| Endpoint | Device Type | Применимость |
|---|---|---|
| 0 | Aggregator (0x000E) | Все типы (корневая точка) |
| 1 | Extended Color Light (0x010D) | Типы 1, 3 |
| 2 | Temperature Sensor (0x0302) | Типы 1, 2 |
| 3 | Humidity Sensor (0x0307) | Типы 1, 2 |

**Примечание:** Extended Color Light используется вместо Fan, так как спецификация Matter на момент написания не включает отдельный тип для вентилятора. Управление скоростью реализуется через атрибут `CurrentLevel`.

**Кластеры и атрибуты**

*Endpoint 1 — Extended Color Light (типы 1, 3):*

| Кластер | Обязательность | Атрибуты и команды |
|---|---|---|
| Identify (0x0003) | Обязательный | `Identify` — визуальная идентификация устройства |
| On/Off (0x0006) | Обязательный | `OnOff` — состояние; команды `On`, `Off`, `Toggle` |
| Level Control (0x0008) | Обязательный | `CurrentLevel` — скважность ШИМ; команда `MoveToLevel` |
| Groups (0x0004) | Обязательный | Групповое управление |

*Endpoint 2 — Temperature Sensor (типы 1, 2):*

| Кластер | Обязательность | Атрибуты |
|---|---|---|
| Temperature Measurement (0x0402) | Обязательный | `MeasuredValue` — текущая температура |

*Endpoint 3 — Humidity Sensor (типы 1, 2):*

| Кластер | Обязательность | Атрибуты |
|---|---|---|
| Relative Humidity Measurement (0x0405) | Обязательный | `MeasuredValue` — текущая влажность |

*Общие кластеры (все конечные точки):*

| Кластер | Назначение |
|---|---|
| Descriptor (0x001D) | Идентификация типа устройства и состава конечной точки |
| Basic Information (0x0028) | `VendorName`, `ProductName`, `SoftwareVersion`, причина перезагрузки |
| OTA Software Update (0x002A) | Обновление прошивки по воздуху |

*Пользовательские параметры:*

Пороги датчика, таймеры и настройки режимов вынесены в пользовательский кластер на Endpoint 0 (Aggregator):

| Кластер | Атрибуты |
|---|---|
| Custom (0xFC00) | `SensorControlMode`, `AdaptiveMode`, `LowTemp`, `HighTemp`, `LowHum`, `HighHum`, `DelaySeconds`, `MaxOnTime` |

**Типы взаимодействия**

| Кластер | Публикация | Управление |
|---|---|---|
| On/Off | Да. Подписка на атрибут `OnOff` | Да. Команды `On`, `Off`, `Toggle` |
| Level Control | Да. Подписка на атрибут `CurrentLevel` | Да. Команда `MoveToLevel` |
| Temperature Measurement | Да. Подписка на атрибут | Нет |
| Relative Humidity Measurement | Да. Подписка на атрибут | Нет |
| Basic Information | Да. Статические атрибуты | Нет |
| OTA Software Update | Нет | Да. Приём обновлений |
| Custom | Да. Подписка на атрибуты | Да. `WriteAttribute` |

**Особенности:**
- Matter использует модель «подписок» (subscriptions) вместо периодической публикации: контроллер подписывается на атрибуты и получает обновления при их изменении.
- Устройство поддерживает multi-admin: одновременную работу с несколькими экосистемами (Apple Home, Google Home, Amazon Alexa и др.).
- Настройка выполняется через стандартную процедуру комиссионинга (commissioning) с QR-кодом или числовым кодом.
- OTA-обновления инициируются со стороны Matter-контроллера.

#### WEB-интерфейс

WEB-интерфейс предоставляет прямой доступ к настройке и управлению устройством через браузер. Доступен по HTTP.

**Режимы доступа:**

| Режим | Адрес | Условия доступа |
|---|---|---|
| Обычный режим | IP-адрес устройства в локальной сети | Устройство подключено к WiFi |
| Режим настройки | `192.168.4.1` | Устройство в режиме точки доступа |

**Страницы веб-интерфейса:**

| Страница | Назначение | Особенности |
|---|---|---|
| `/` | Страница состояния | Текущие показания датчиков, статус исполнительного механизма, активные режимы, оставшееся время до аварийного отключения |
| `/config` | Страница настройки | Форма изменения параметров WiFi, MQTT, порогов датчиков, таймеров |
| `/save` | Сохранение настроек | Принимает POST-запрос из формы `/config`, сохраняет параметры в EEPROM, перезагружает устройство |
| `/update` | OTA-обновление | Загрузка файла прошивки, автоматическая перезагрузка после обновления |

**Особенности:**
- Только изменения, сохранённые через `/config` → `/save`, записываются в энергонезависимую память.
- Оперативные команды (включение/выключение, смена режима, изменение скважности) действуют до перезагрузки.
- OTA-обновление является единственным способом обновления прошивки без демонтажа устройства.

## TODO

### Архитектурный долг (запланирован на будущее)

### Функциональные вопросы

- [ ] Реализовать включение не только в заданных диапазонах температуры и влажности, но и при скачке показаний, с учетом направления - вырос на некую величину после получения первых показаний -> включить, падают - выключить. Продумать как это сделать и какая должна быть величина этого скачка.
- [x] Все магические величины должны быть прописаны в константах
- [ ] Реализовать поэтапное увеличение скорости при работе по таймеру: каждые `delaySeconds` секунд увеличивать `speedPercent` на 20% до 100% (актуально для туалета, когда датчик молчит). Частично сделано - введены сущности `*rampUp*`
- [x] Исправить: для типа 2/3 ошибки в названиях топиков. 
- [x] Реализовать кастомные пины для I2C - нужна инициализация
- [x] В web нет отображения оставшегося времени и состояния таймеров
- [x] Расширить понимаемые значения для MQTT reset - до `RESET`,`ON`,`TRUE` и задокументировать это 
- [x] Исправить отсутствие публикации MQTT значений для датчика и выключателя, rssi, версии и др

### Покрытие документацией

- [ ] Раскрыть в документации особенности реализации адаптивного режима
- [ ] Задокументировать mqttUser и mqttPassword в конфигурации
- [ ] Задокументировать параметры ШИМ, не описанные в документации - `PWM_FREQUENCY`,`PWM_RESOLUTION`
- [ ] Задокументировать параметры Параметры WDT `WDT_TIMER_MS`,`LOOP_WATCHDOG_MULTIPLIER`
- [x] Задокументировать режимы отладки и логирования
- [ ] Задокументировать принципы вычисления скорости в адаптивном режиме
- [ ] Задокументировать периодическую публикацию Heartbeat
- [ ] Задокументировать умолчания, примеры изменения в platformio:

| # | Что отсутствует/несоответствует | Где в коде |
|---|---|---|
| 1 | `WEB_RESET_ENABLED = 0` по умолчанию не задокументировано | `config.h` |
| 2 | Несоответствие `MIN_SPEED_PERCENT` (док 10, код 1) | `config.h` vs docs | 
| 3 | `STATUS_LED_PIN` не в таблице параметров | `config.h` |
| 4 | `AP_FALLBACK_TIMEOUT_MS` значение по умолчанию не указано | `config.h` | 
| 5 | `WIFI_CONNECT_TIMEOUT_MS` не описан | `config.h` | 
| 6 | `MQTT_KEEPALIVE_SEC` не описан | `config.h` | 
| 7 | `MQTT_RECONNECT_DELAY_MS` не описан | `config.h` | 

### Техническая реализация

- [x] Удалить дублирование кода для `getResetReason()`

### Архитектура

- [x] Инкапсуляция `Config` (геттеры/сеттеры)
- [x] Инкапсуляция `Sensor` (убраны глобальные переменные)
- [x] Рефакторинг `Actuator` (Fan/Switch объединены)
- [x] Реализовать индикацию срабатывания таймера аварийного отключения (серия вспышек длинная (как `LED_MODE_MORZE_E`) - пауза - две коротких (как `LED_MODE_MORZE_I`))
- [x] Реализовать индикацию записи конфигурации (LED выключен)
- [ ] Реализовать адаптивный режим для вентилятора включаемого по таймеру (rampUp)
- [x] В режиме AP реализовать проверку доступности wifi из конфигурации и возврат в нормальный режим в случае восстановления связи

#### Web слой

- [ ] Устранить зависимости web.cpp от глобальных указателей `g_fanActuator`/`g_switchActuator`
- [ ] Устранить #if DEVICE_TYPE из `web_buildStatusHtml()`
- [ ] Устранить прямые вызовы `sensor_*()` и `config_get()` из `web.cpp`
- [ ] Внедрить передачу данных через параметры (структуры `SensorReading`, `ActuatorStatus`, и т.д.)

#### Общее состояние

- [ ] Создать единый `StateHolder` или использовать паттерн `Repository` для агрегации состояния устройства
- [ ] Устранить глобальные переменные (`deviceId`, `apMode`) — инкапсулировать в `StateHolder`

### Discovery

- [ ] **Ввести абстракцию Discovery для отделения логики обнаружения от транспорта**
- [ ] Создать интерфейс `Discovery` (pure virtual class)
- [ ] Реализовать `MqttDiscovery` с поддержкой Home Assistant и openHAB
- [ ] Реализовать `ZigbeeDiscovery` (для ESP32-C6)
- [ ] Реализовать `MatterDiscovery` (для ESP32-C6 + Thread)
- [ ] Интегрировать Discovery в `main.cpp` (создаётся в зависимости от транспорта)

#### MQTT Discovery

- [ ] Добавить `publishDiscovery()` в MQTTManager
- [ ] Поддержать `retain` флаг для конфигурационных топиков
- [ ] Реализовать Device, Fan, Sensor, Switch сущности
- [ ] Добавить поддержку `availability_topic` (уже есть)
- [ ] Протестировать с Home Assistant
- [ ] Протестировать с openHAB (возможно, потребуется отдельный префикс)

#### Zigbee / Matter (перспектива)

- [ ] Исследовать ESP-Zigbee-SDK / ESP-Matter
- [ ] Создать отдельные реализации Discovery для этих протоколов
- [ ] Интегрировать с существующей бизнес-логикой (FanActuator, Sensor)

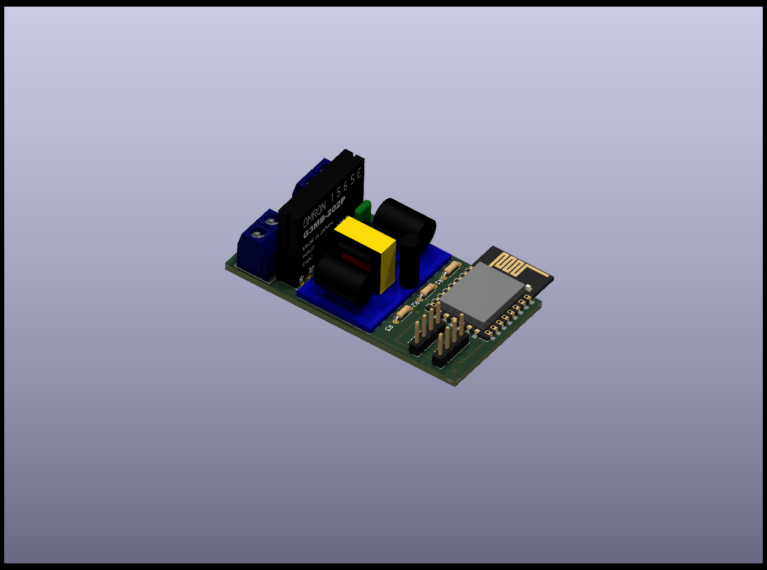
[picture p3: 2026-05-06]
Fan/Fan.png

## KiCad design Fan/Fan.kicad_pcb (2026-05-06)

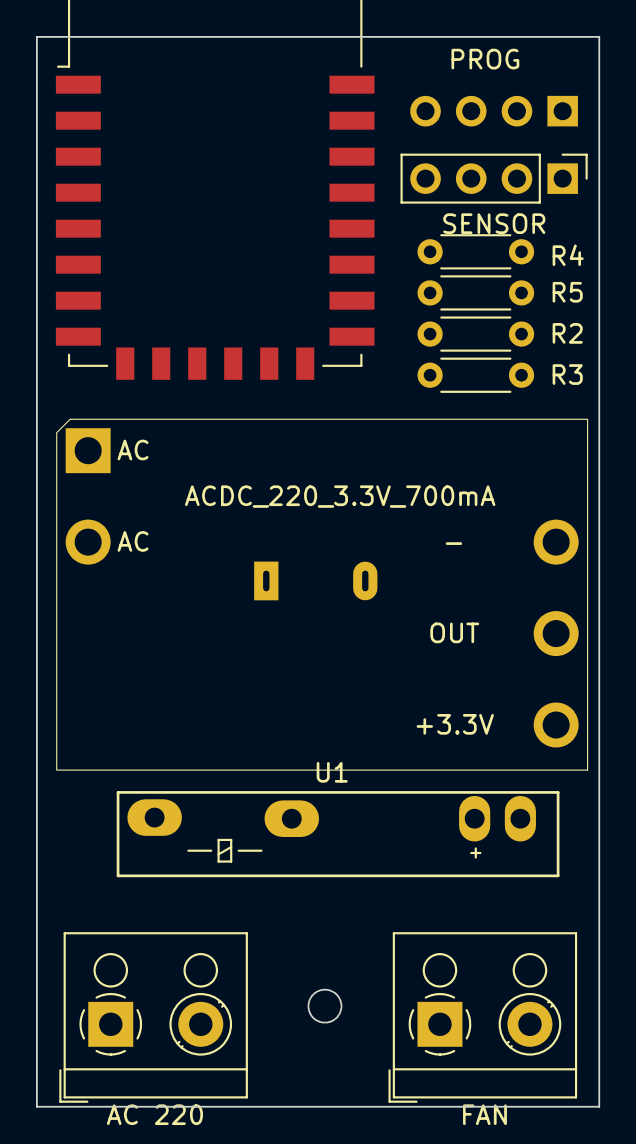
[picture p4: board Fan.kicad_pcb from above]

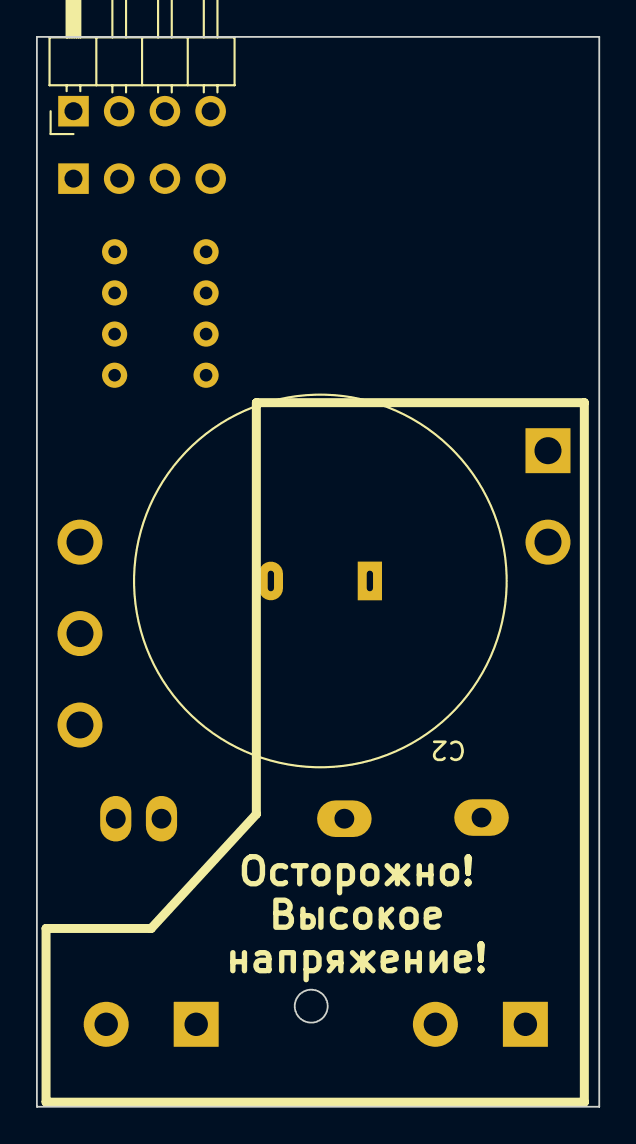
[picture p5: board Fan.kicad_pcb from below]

Board: 2 copper layers, 31.2 x 59.4 mm, 12 parts (2 on the bottom side), 12 nets, no tracks yet.

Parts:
C2: 4F; C_Radial_D20.4mm_H7.0mm_P6.8mm
J1: PROG; PinHeader_1x04_P2.54mm_Horizontal
J2: SENSOR; PinHeader_1x04_P2.54mm_Vertical
M1: ACDC_220_3.3V_700mA; Converter_ADCD_China
R2, R3, R4, R5: 10K; R_Axial_DIN0204_L3.6mm_D1.6mm_P5.08mm_Horizontal
SW1: AC 220; TerminalBlock_RND_205-00001_1x02_P5.00mm_Horizontal
SW2: FAN; TerminalBlock_RND_205-00001_1x02_P5.00mm_Horizontal
U1: G5MB-202P; Relay_SPDT_Omron-G3MB
U2: ESP-12F; ESP-12E

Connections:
/RXD: J1.4, U2.21 (GPIO3/RXD)
/SCL: J2.4, U2.20 (GPIO5)
/SDA: J2.2, U2.19 (GPIO4)
/TXD: J1.3, U2.22 (GPIO1/TXD)
AC: M1.1 (AC(L)), M1.2 (AC(N)), SW1.1, SW1.2, SW2.1, U1.1
GND: C2.2, J1.2, J2.3, M1.6 (Vout-), R5.2, U1.4, U2.15 (GND)
unnamed: R3.2, U2.1 (~RST)
unnamed: R4.2, U2.3 (EN)
unnamed: R5.1, U2.16 (GPIO15)
unnamed: SW2.2, U1.2
unnamed: U1.3, U2.5 (GPIO14)
VCC: J1.1, J2.1, M1.8 (Vout+), R2.1, R3.1, R4.1, U2.8 (VCC)

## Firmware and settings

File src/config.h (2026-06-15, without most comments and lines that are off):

#define CONFIG_H
#include <Arduino.h>
#include <EEPROM.h>
#define VERSION "1.0"
#define DEVICE_TYPE 1
#define RESET_PIN 0
#define STATUS_LED_PIN 0
#ifdef ESP8266
#define I2C_SDA_PIN 4
#elif defined(ESP32)
#define I2C_SDA_PIN 21
#endif
#ifdef ESP8266
#define I2C_SCL_PIN 5
#elif defined(ESP32)
#define I2C_SCL_PIN 22
#endif
#ifdef ESP8266
#define SWITCH_PIN 14
#elif defined(ESP32)
#define SWITCH_PIN 4
#endif
#define ACTIVE_LEVEL LOW
#if DEVICE_TYPE == 1
#define DEVICE_PREFIX "fan"
#elif DEVICE_TYPE == 2
#define DEVICE_PREFIX "sensor"
#elif DEVICE_TYPE == 3
#define DEVICE_PREFIX "switch"
#else
#define DEVICE_PREFIX "device"
#endif
#define SENSOR_TYPE 1
#if SENSOR_TYPE == 2
#ifdef ESP8266
#define SENSOR_PIN 4
#elif defined(ESP32)
#define SENSOR_PIN 16
#endif
#endif
#define WIFI_ENABLED 1
#define SCANING_WIFI_ENABLED 0
#define AP_ENABLED 1
#define WEB_STATUS_ENABLED 1
#define MQTT_ENABLED 1
#define OTA_ENABLED 1
#define WDT_ENABLED 1
#define PWM_ENABLED 1
#define ADAPTIVE_ENABLED 1
#define EMERGENCY_ENABLED 1
#define WDT_TIMER_MS 5000
#define PWM_FREQUENCY 5
#define PWM_RESOLUTION 8
#define PWM_STARTING 200
#define ADAPTIVE_EPSILON_TEMP 0.5
#define ADAPTIVE_EPSILON_HUM 2.0
#define ADAPTIVE_SPEED_SENSITIVITY 0.7
#define ADAPTIVE_STEP_SIZE 10
#define MIN_SPEED_PERCENT 1
#define LOG_LEVEL 3
#define LOG_CATEGORIES 0xFFFF
#define LOG_USE_COLOR 1
#define MQTT_RECONNECT_DELAY_MS 5000
#define STATE_PUBLISH_INTERVAL_MS 3000
#define MQTT_KEEPALIVE_SEC 3
#define MQTT_RESET_ENABLED 1
#define MQTT_PUBLISH_RSSI 1
#define MQTT_PUBLISH_VERSION 1
#define MQTT_PUBLISH_RESET_REASON 1
#define AP_IP_ADDRESS "192.168.4.1"
#define AP_FALLBACK_TIMEOUT_MS 12000
#define WIFI_CONNECT_TIMEOUT_MS 30000
#define WEB_SHOW_RSSI 1
#define DEFAULT_WEB_REFRESH 5
#define DEVICE_ID_MAX_LEN 24
#define WIFI_SSID_MAX_LEN 32
#define WIFI_PASSWORD_MAX_LEN 64
#define MQTT_BROKER_MAX_LEN 64
#define MQTT_USER_MAX_LEN 32
#define MQTT_PASSWORD_MAX_LEN 64
#define TEMP_MIN -40.0
#define TEMP_MAX 85.0
#define HUM_MIN 0.0
#define HUM_MAX 100.0
#define SENSOR_INTERVAL_MIN 1
#define SENSOR_INTERVAL_MAX 3600
#define DELAY_SECONDS_MIN 0
#define DELAY_SECONDS_MAX 86400
#define MAX_ON_TIME_MIN 0
#define MAX_ON_TIME_MAX 86400
#define SPEED_PERCENT_MIN 0
#define SPEED_PERCENT_MAX 100
#define DEFAULT_WIFI_SSID ""
#define DEFAULT_WIFI_PASSWORD ""
#define DEFAULT_MQTT_BROKER ""
#define DEFAULT_MQTT_PORT 1883
#define DEFAULT_MQTT_USER ""
#define DEFAULT_MQTT_PASSWORD ""
#define DEFAULT_SENSOR_INTERVAL 10
#define DEFAULT_LOW_TEMP 27.0
#define DEFAULT_HIGH_TEMP 29.0
#define DEFAULT_LOW_HUM 55.0
#define DEFAULT_HIGH_HUM 60.0
#define DEFAULT_SENSOR_CONTROL_MODE true
#define DEFAULT_SPEED_PERCENT 50
#define DEFAULT_ADAPTIVE_MODE false
#define DEFAULT_DELAY_SECONDS 60
#define DEFAULT_MAX_ON_TIME 3600
#define DEFAULT_BOOT_STATE true
#ifdef __has_include
#if __has_include("credentials.h")
#include "credentials.h"
#define HAS_CREDENTIALS 1
#else
#define HAS_CREDENTIALS 0
#endif
#else
#ifdef CREDENTIALS_AVAILABLE
#include "credentials.h"
#define HAS_CREDENTIALS 1
#else
#define HAS_CREDENTIALS 0
#endif
#endif
#define SSID_NAME ""
#define WIFI_PASSWORD ""
#define MQTT_ADDRESS ""
#define MQTT_PORT 1883
#define MQTT_USER ""
#define MQTT_PASSWORD ""
#define MAGIC_VALUE 0x5A6B
extern bool apMode;
enum TransportType {
  TRANSPORT_NONE = 0,
  TRANSPORT_MQTT = 1,
  TRANSPORT_ZIGBEE = 2,
  TRANSPORT_MATTER = 3
};
#define TRANSPORT_TYPE TRANSPORT_NONE
struct Config {
  uint16_t magic;                    //!< Магическое число (MAGIC_VALUE)
  uint16_t crc;                      //!< CRC16 от всех полей
  char deviceId[DEVICE_ID_MAX_LEN];  //!< Уникальный ID устройства
  char wifiSsid[WIFI_SSID_MAX_LEN];          //!< Имя WiFi сети
  char wifiPassword[WIFI_PASSWORD_MAX_LEN];  //!< Пароль WiFi
#if TRANSPORT_TYPE == TRANSPORT_MQTT
  char mqttBroker[MQTT_BROKER_MAX_LEN];      //!< Адрес MQTT брокера
  uint16_t mqttPort;                         //!< Порт MQTT брокера (1-65535)
  char mqttUser[MQTT_USER_MAX_LEN];          //!< Имя пользователя MQTT
  char mqttPassword[MQTT_PASSWORD_MAX_LEN];  //!< Пароль MQTT
#elif TRANSPORT_TYPE == TRANSPORT_ZIGBEE
  uint16_t zigbeePanId;     //!< Zigbee PAN ID
  uint8_t zigbeeChannel;    //!< Zigbee канал (11-26)
  char zigbeeDeviceId[16];  //!< Zigbee идентификатор устройства
#elif TRANSPORT_TYPE == TRANSPORT_MATTER
  char matterSetupCode[32];    //!< Matter setup code
  char matterVendorName[32];   //!< Имя вендора
  char matterProductName[32];  //!< Имя продукта
#endif
#if DEVICE_TYPE == 1 || DEVICE_TYPE == 2
  uint16_t sensorInterval;  //!< Интервал опроса датчика (сек)
#endif
#if DEVICE_TYPE == 1
  double lowHum;           //!< Нижний порог влажности (%)
  double highHum;          //!< Верхний порог влажности (%)
  double lowTemp;          //!< Нижний порог температуры (°C)
  double highTemp;         //!< Верхний порог температуры (°C)
  bool sensorControlMode;  //!< Режим управления сенсором
  uint16_t speedPercent;   //!< Скорость вентилятора (%)
  bool adaptiveMode;       //!< Адаптивный тихий режим
#endif
#if DEVICE_TYPE == 1 || DEVICE_TYPE == 3
  int delaySeconds;    //!< Задержка отложенного включения (сек)
  uint32_t maxOnTime;  //!< Таймер аварийного отключения (сек)
  bool bootState;      //!< Состояние при старте
#endif
  bool valid;      //!< Флаг валидности конфига
  char error[64];  //!< Текст ошибки (при valid == false)
  Config();
};
void config_init();
Config config_load();
bool config_save(const Config& cfg);
Config config_getDefaults();
static bool isValidString(const char* str, bool allowEmpty);
bool config_validate(Config& cfg);
uint16_t crc16(const uint8_t* data, size_t len);
void config_print(const Config& cfg);
bool config_setDeviceId(const char* deviceId);
bool config_setWifiSsid(const char* ssid);
bool config_setWifiPassword(const char* password);
#if MQTT_ENABLED == 1
bool config_setMqttBroker(const char* broker);
bool config_setMqttPort(uint16_t port);
bool config_setMqttUser(const char* user);
bool config_setMqttPassword(const char* password);
#endif
#if DEVICE_TYPE == 1 || DEVICE_TYPE == 3
bool config_setDelaySeconds(int seconds);
bool config_setMaxOnTime(uint32_t seconds);
bool config_setBootState(bool state);
#endif
#if DEVICE_TYPE == 1 || DEVICE_TYPE == 2
bool config_setSensorInterval(uint16_t interval);
#endif
#if DEVICE_TYPE == 1
bool config_setLowTemp(double temp);
bool config_setHighTemp(double temp);
bool config_setLowHum(double hum);
bool config_setHighHum(double hum);
bool config_setSensorControlMode(bool enabled);
bool config_setSpeedPercent(uint16_t percent);
bool config_setAdaptiveMode(bool enabled);
#endif

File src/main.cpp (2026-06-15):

// ============================================================================
// @file main.cpp
// @brief Главный модуль, оркестратор устройства
// ============================================================================

#include <Arduino.h>
#include "config.h"
#include "led.h"
#include "logger.h"
#include "web.h"
#include "wifi_manager.h"

#ifdef ESP32
#include <esp_chip_info.h>
#endif

// ============================================================================
// ПОДКЛЮЧЕНИЕ МОДУЛЕЙ (по флагам компиляции)
// ============================================================================

#if MQTT_ENABLED == 1
#include "mqtt.h"
static WiFiClient g_mqttClient;
#endif

#if WDT_ENABLED == 1
#include "wdt_manager.h"
#endif

#if DEVICE_TYPE == 1
#include "fan_actuator.h"
#elif DEVICE_TYPE == 3
#include "switch_actuator.h"
#endif

#if DEVICE_TYPE == 1 || DEVICE_TYPE == 2
#include "sensor.h"
#endif

// ============================================================================
// ГЛОБАЛЬНЫЕ ПЕРЕМЕННЫЕ
// ============================================================================

bool apMode = false;
static Config g_activeConfig;

// ============================================================================
// ОБЪЕКТЫ АКТУАТОРОВ
// ============================================================================

#if DEVICE_TYPE == 1
static FanActuator fan;
static unsigned long lastAdaptiveCheck = 0;
static float baseTemp = 0;
static float baseHum = 0;
static bool adaptiveActive = false;
#elif DEVICE_TYPE == 3
static SwitchActuator switchActuator;
#endif

// ============================================================================
// ТАЙМЕРЫ ОРКЕСТРАТОРА
// ============================================================================

#if DEVICE_TYPE == 1 || DEVICE_TYPE == 3
static unsigned long delayTimerExpiry = 0;
static bool delayActive = false;
#endif

// ============================================================================
// ВСПОМОГАТЕЛЬНЫЕ ФУНКЦИИ
// ============================================================================

static bool isAutoModeEnabled() {
  return g_activeConfig.sensorControlMode && sensor_isOk();
}

// ============================================================================
// ЛОГИКА УПРАВЛЕНИЯ ВЕНТИЛЯТОРОМ (TYPE 1)
// ============================================================================

#if DEVICE_TYPE == 1

static void processSensorControl() {
  static bool lastAutoWasWorking = false;
  bool autoEnabled = isAutoModeEnabled();

  if (autoEnabled != lastAutoWasWorking) {
    if (autoEnabled) {
      LOG_INFO(CAT_SENSOR, "Sensor control mode ACTIVE (sensor OK)");
    } else {
      if (!sensor_isOk()) {
        LOG_WARN(CAT_SENSOR,
                 "Sensor control mode DISABLED: sensor not available");
      } else if (!g_activeConfig.sensorControlMode) {
        LOG_INFO(CAT_SENSOR, "Sensor control mode DISABLED: user turned off");
      }
    }
    lastAutoWasWorking = autoEnabled;
  }

  if (!autoEnabled)
    return;

  float temp = sensor_getTemperature();
  float hum = sensor_getHumidity();

  bool shouldBeOn =
      (temp >= g_activeConfig.highTemp || hum >= g_activeConfig.highHum);
  bool shouldBeOff =
      (temp <= g_activeConfig.lowTemp && hum <= g_activeConfig.lowHum);

  if (shouldBeOn && !fan.getState()) {
    LOG_INFO(CAT_SENSOR, "Auto ON: T=%.1f°C H=%.1f%%", temp, hum);
    fan.set(true, false);
    adaptiveActive = false;
  } else if (shouldBeOff && fan.getState()) {
    LOG_INFO(CAT_SENSOR, "Auto OFF: T=%.1f°C H=%.1f%%", temp, hum);
    fan.set(false, false);
    adaptiveActive = false;
  }
}

static void processAdaptiveMode() {
  if (!g_activeConfig.adaptiveMode)
    return;
  if (!isAutoModeEnabled())
    return;
  if (!fan.getState())
    return;

  unsigned long interval = g_activeConfig.sensorInterval * 1000UL;
  if (millis() - lastAdaptiveCheck < interval)
    return;
  lastAdaptiveCheck = millis();

  if (!adaptiveActive) {
    adaptiveActive = true;
    baseTemp = sensor_getTemperature();
    baseHum = sensor_getHumidity();
    LOG_DEBUG(CAT_FAN, "Adaptive mode activated: base T=%.1f°C, H=%.1f%%",
              baseTemp, baseHum);
    return;
  }

  float deltaTemp = sensor_getTemperature() - baseTemp;
  float deltaHum = sensor_getHumidity() - baseHum;
  float humRate = sensor_getHumRate();

  int step = ADAPTIVE_STEP_SIZE;
  if (deltaTemp > ADAPTIVE_EPSILON_TEMP * 2 ||
      deltaHum > ADAPTIVE_EPSILON_HUM * 2)
    step *= 2;
  if (deltaTemp > ADAPTIVE_EPSILON_TEMP * 3 ||
      deltaHum > ADAPTIVE_EPSILON_HUM * 3)
    step *= 3;

  float mult = 1.0 + (humRate / ADAPTIVE_SPEED_SENSITIVITY);
  mult = constrain(mult, 0.5, 3.0);
  step = step * mult;
  step = constrain(step, 5, 60);

  if (deltaTemp > ADAPTIVE_EPSILON_TEMP || deltaHum > ADAPTIVE_EPSILON_HUM) {
    int newSpeed = fan.getSpeed() + step;
    if (newSpeed > 100)
      newSpeed = 100;
    if (newSpeed != fan.getSpeed()) {
      fan.setSpeed(newSpeed, false);
      baseTemp = sensor_getTemperature();
      baseHum = sensor_getHumidity();
      LOG_DEBUG(CAT_FAN, "Adaptive: speed %d%% (ΔT=%.1f, ΔH=%.1f, rate=%.2f)",
                newSpeed, deltaTemp, deltaHum, humRate);
    }
  }
}

#endif  // DEVICE_TYPE == 1

// ============================================================================
// ЛОГИКА ТАЙМЕРА ОТЛОЖЕННОГО ВКЛЮЧЕНИЯ (TYPE 1 и 3)
// ============================================================================

#if DEVICE_TYPE == 1 || DEVICE_TYPE == 3

static void processDelayTimer() {
  if (delayActive && !fan.getState() && g_activeConfig.delaySeconds > 0) {
    if (millis() >= delayTimerExpiry) {
      delayActive = false;
      LOG_INFO(CAT_ACTUATOR, "Delay timer expired, turning ON");
      fan.set(true, false);
    }
    return;
  }

  if (!delayActive && !fan.getState() && g_activeConfig.delaySeconds > 0) {
    delayActive = true;
    delayTimerExpiry = millis() + g_activeConfig.delaySeconds * 1000UL;
    LOG_INFO(CAT_ACTUATOR, "Delay timer started: %d sec",
             g_activeConfig.delaySeconds);
    return;
  }

  if (delayActive && fan.getState()) {
    delayActive = false;
    LOG_INFO(CAT_ACTUATOR, "Delay timer cancelled (manual ON)");
  }
}

#endif  // DEVICE_TYPE == 1 || DEVICE_TYPE == 3

// ============================================================================
// ПРИМЕНЕНИЕ КОНФИГУРАЦИИ (для нормального режима)
// ============================================================================

static void applyNormalModeConfig() {
  LOG_INFO(CAT_MAIN, "Applying normal mode configuration...");

#if MQTT_ENABLED == 1
  mqttManager.begin(g_mqttClient, g_activeConfig.mqttBroker,
                    g_activeConfig.mqttPort, g_activeConfig.mqttUser,
                    g_activeConfig.mqttPassword);
  LOG_DEBUG(CAT_MAIN, "MQTT initialized: broker=%s:%d",
            g_activeConfig.mqttBroker, g_activeConfig.mqttPort);
#endif

#if WDT_ENABLED == 1
  wdt_init();
  LOG_DEBUG(CAT_MAIN, "WDT initialized, timeout=%d ms", WDT_TIMER_MS);
#endif

  LOG_INFO(CAT_MAIN, "Normal mode configuration applied");
}

// ============================================================================
// SETUP
// ============================================================================

void setup() {
  // 1. Инициализация логгера
  Logger::getInstance().begin((LogLevel)LOG_LEVEL, LOG_CATEGORIES,
                              LOG_USE_COLOR);

  LOG_INFO(CAT_MAIN, "==========================================");
  LOG_INFO(CAT_MAIN, "SYSTEM START");
  LOG_DEBUG(CAT_MAIN, "=== SYSTEM INFO ===");

#ifdef ESP32
  LOG_DEBUG(CAT_MAIN, "Platform: ESP32");
  esp_chip_info_t chip_info;
  esp_chip_info(&chip_info);
  LOG_DEBUG(CAT_MAIN, "Chip model: ESP32-%d", chip_info.model);
  LOG_DEBUG(CAT_MAIN, "Chip revision: %d", chip_info.revision);
  LOG_DEBUG(CAT_MAIN, "Cores: %d", chip_info.cores);
  LOG_DEBUG(CAT_MAIN, "CPU frequency: %d MHz", getCpuFrequencyMhz());
  LOG_DEBUG(CAT_MAIN, "Chip ID: %08X", (uint32_t)ESP.getEfuseMac());
  uint32_t flashSize = ESP.getFlashChipSize();
  LOG_DEBUG(CAT_MAIN, "Flash chip size: %u bytes (%u MB)", flashSize,
            flashSize / (1024 * 1024));
  LOG_DEBUG(CAT_MAIN, "Flash chip speed: %d MHz",
            ESP.getFlashChipSpeed() / 1000000);
  LOG_DEBUG(CAT_MAIN, "Flash chip mode: %d", ESP.getFlashChipMode());
#ifdef CONFIG_SPIRAM_SUPPORT
  LOG_DEBUG(CAT_MAIN, "PSRAM size: %u bytes", ESP.getPsramSize());
  LOG_DEBUG(CAT_MAIN, "Free PSRAM: %u bytes", ESP.getFreePsram());
#else
  LOG_DEBUG(CAT_MAIN, "PSRAM: not supported/enabled");
#endif
  LOG_DEBUG(CAT_MAIN, "Free heap: %u bytes", ESP.getFreeHeap());
  LOG_DEBUG(CAT_MAIN, "Minimum free heap: %u bytes", ESP.getMinFreeHeap());
  LOG_DEBUG(CAT_MAIN, "Maximum allocatable heap: %u bytes",
            ESP.getMaxAllocHeap());
  LOG_DEBUG(CAT_MAIN, "ESP-IDF version: %s", esp_get_idf_version());
#elif defined(ESP8266)
  LOG_DEBUG(CAT_MAIN, "Platform: ESP8266");
  LOG_DEBUG(CAT_MAIN, "Chip ID: %08X", ESP.getChipId());
  LOG_DEBUG(CAT_MAIN, "Core version: %s", ESP.getCoreVersion().c_str());
  LOG_DEBUG(CAT_MAIN, "CPU frequency: %d MHz", ESP.getCpuFreqMHz());
  LOG_DEBUG(CAT_MAIN, "Free heap: %u bytes", ESP.getFreeHeap());
  uint32_t flashSize = ESP.getFlashChipSize();
  LOG_DEBUG(CAT_MAIN, "Flash chip size: %u bytes (%u MB)", flashSize,
            flashSize / (1024 * 1024));
  uint32_t realFlashSize = ESP.getFlashChipRealSize();
  if (realFlashSize > 0 && realFlashSize != flashSize) {
    LOG_DEBUG(CAT_MAIN, "Real flash chip size: %u bytes (%u MB)", realFlashSize,
              realFlashSize / (1024 * 1024));
  }
  LOG_DEBUG(CAT_MAIN, "Flash chip speed: %d MHz",
            ESP.getFlashChipSpeed() / 1000000);
  LOG_DEBUG(CAT_MAIN, "Flash chip mode: %d (0=QIO, 1=QOUT, 2=DIO, 3=DOUT)",
            ESP.getFlashChipMode());
  LOG_DEBUG(CAT_MAIN, "SDK version: %s", system_get_sdk_version());
#endif

  LOG_DEBUG(CAT_MAIN, "==========================================");
  LOG_DEBUG(CAT_MAIN, "Sketch size: %u bytes", ESP.getSketchSize());
  LOG_DEBUG(CAT_MAIN, "Free sketch space: %u bytes", ESP.getFreeSketchSpace());
  LOG_DEBUG(CAT_MAIN, "Free heap: %u bytes", ESP.getFreeHeap());
  LOG_DEBUG(CAT_MAIN, "Firmware version: %s", VERSION);
  LOG_INFO(CAT_MAIN, "==========================================");
  LOG_INFO(CAT_MAIN, "Device starting with %s mode", DEVICE_PREFIX);

  // 2. Инициализация LED
  led_init();
  led_setMode(LED_MODE_MORZE_E);
  led_update();
  LOG_DEBUG(CAT_MAIN, "LED initialized, pin=%d", STATUS_LED_PIN);

  // 3. Инициализация WiFi стека
  wifi_init();

  // 4. Инициализация конфигурации
  config_init();
  g_activeConfig = config_load();

  // 5. Инициализация датчика (всегда)
#if DEVICE_TYPE == 1 || DEVICE_TYPE == 2
  sensor_init(&g_activeConfig);
  LOG_DEBUG(CAT_MAIN, "Sensor initialized: interval=%d sec, type=%d",
            g_activeConfig.sensorInterval, SENSOR_TYPE);

  if (!sensor_isOk()) {
    LOG_WARN(CAT_SENSOR, "Sensor not available: %s", sensor_getError());
    if (g_activeConfig.sensorControlMode) {
      LOG_WARN(CAT_MAIN,
               "Sensor control mode temporarily disabled (no sensor)");
    }
  }
#endif

  // 6. Инициализация актуатора (всегда)
#if DEVICE_TYPE == 1
  fan.init(SWITCH_PIN, g_activeConfig.bootState, g_activeConfig.speedPercent,
           g_activeConfig.maxOnTime);
  LOG_INFO(CAT_MAIN, "Fan initialized: speed=%d%%, maxOnTime=%lu sec",
           g_activeConfig.speedPercent, g_activeConfig.maxOnTime);
#elif DEVICE_TYPE == 3
  switchActuator.init(SWITCH_PIN, g_activeConfig.bootState,
                      g_activeConfig.maxOnTime);
  LOG_INFO(CAT_MAIN, "Switch initialized: maxOnTime=%lu sec",
           g_activeConfig.maxOnTime);
#endif

  // ========== НАСТРОЙКА КОНТЕКСТА ДЛЯ ВЕБ-СЛОЯ ==========
  web_setTransport((TransportType)TRANSPORT_TYPE);
  web_setDeviceType(DEVICE_TYPE);
  web_setConfig(&g_activeConfig);

  // 7. Проверка валидности конфига и выбор режима
  if (!g_activeConfig.valid) {
    LOG_ERROR(CAT_MAIN, "Config is INVALID: %s", g_activeConfig.error);
    LOG_INFO(CAT_MAIN, "Using defaults, entering AP mode for setup");

    g_activeConfig = config_getDefaults();
    apMode = true;

    // Запускаем AP режим (открытая сеть)
    wifi_startAP(g_activeConfig.deviceId, nullptr);
    web_setApMode(true);
    web_enableStatusPage(false);  // корень → конфиг
    web_init();
    led_setMode(LED_MODE_MORZE_S);
    LOG_INFO(CAT_MAIN, "AP mode active. SSID: %s, IP: %s (open)",
             g_activeConfig.deviceId, AP_IP_ADDRESS);
  } else {
    LOG_INFO(CAT_MAIN, "Config is VALID, entering normal mode");
    apMode = false;

    // Подключаемся к WiFi
    if (strlen(g_activeConfig.wifiSsid) > 0) {
      wifi_connect(g_activeConfig.wifiSsid, g_activeConfig.wifiPassword);
    } else {
      LOG_WARN(CAT_MAIN, "WiFi SSID is empty, staying in AP mode");
      apMode = true;
      wifi_startAP(g_activeConfig.deviceId, nullptr);
      web_setApMode(true);
      web_enableStatusPage(false);
      web_init();
      led_setMode(LED_MODE_MORZE_S);
    }

    web_setApMode(false);
    web_enableStatusPage(WEB_STATUS_ENABLED == 1);
    web_init();

    applyNormalModeConfig();
    led_setMode(LED_MODE_ON);
  }

  config_print(g_activeConfig);
  LOG_INFO(CAT_MAIN, "==========================================");
  LOG_INFO(CAT_MAIN, "Setup complete. Entering loop()");
  LOG_INFO(CAT_MAIN, "==========================================");
}

// ============================================================================
// LOOP
// ============================================================================

void loop() {
  led_update();

#if WDT_ENABLED == 1
  wdt_feed();
#endif

  // 1. Чтение датчика
#if DEVICE_TYPE == 1 || DEVICE_TYPE == 2
  sensor_update();
#endif

  // 2. Логика управления актуаторами
#if DEVICE_TYPE == 1
  processSensorControl();
  processAdaptiveMode();
  processDelayTimer();
  fan.update();

  if (fan.isEmergencyStop()) {
    led_setMode(LED_SLOW_BLINK);
  }
#elif DEVICE_TYPE == 3
  processDelayTimer();
  switchActuator.update();

  if (switchActuator.isEmergencyStop()) {
    led_setMode(LED_SLOW_BLINK);
  }
#endif

  // 3. Передача данных в веб-слой
  web_setSensorData(sensor_getTemperature(), sensor_getHumidity());
  web_setActuatorState(fan.getState(), fan.getSpeed());

  // 4. Обработка WiFi
  wifi_process();

  // 5. Веб-сервер
  web_update();

  // 6. MQTT (только в нормальном режиме и при наличии WiFi)
  // if (!apMode && wifi_isConnected() && MQTT_ENABLED == 1) {
  //   mqttManager.process();
  // }

  delay(10);
}

// ============================================================================
// ТОЧКИ ВХОДА ДЛЯ ВНЕШНИХ МОДУЛЕЙ
// ============================================================================

const Config* config_getActive() {
  return &g_activeConfig;
}

bool config_updateFromWeb(const Config& newConfig) {
  LOG_INFO(CAT_MAIN, "Updating config from web...");

  Config temp = newConfig;
  if (!config_validate(temp)) {
    LOG_ERROR(CAT_MAIN, "Invalid config from web: %s", temp.error);
    return false;
  }

  if (!config_save(temp)) {
    LOG_ERROR(CAT_MAIN, "Failed to save config to EEPROM");
    return false;
  }

  g_activeConfig = temp;
  LOG_INFO(CAT_MAIN, "Config saved successfully, restarting...");
  delay(100);
  ESP.restart();
  return true;
}

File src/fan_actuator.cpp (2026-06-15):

#include "fan_actuator.h"
#include "logger.h"

#ifdef ESP32
#include <esp32-hal-ledc.h>
#endif

static int percentToPWMValue(int percent) {
  if (percent <= 0)
    return 0;
  if (percent >= 100)
    return 255;
  return map(percent, 0, 100, 0, 255);
}

FanActuator::FanActuator()
    : ActuatorBase(),
      _currentSpeed(0),
      _pwmActive(false),
      _startingPulseActive(false),
      _startingPulseStart(0) {}

void FanActuator::init(uint8_t pin,
                       bool bootState,
                       uint16_t defaultSpeed,
                       uint32_t maxOnTime) {
  _currentSpeed = defaultSpeed;
  _pwmActive = false;
  _startingPulseActive = false;

#ifdef ESP32
  ledcSetup(0, PWM_FREQUENCY, PWM_RESOLUTION);
#elif defined(ESP8266)
  analogWriteFreq(PWM_FREQUENCY);
  analogWriteRange(255);
#endif

  ActuatorBase::init(pin, bootState, maxOnTime);
  LOG_INFO(CAT_FAN,
           "Init: speed=%d%%, maxOnTime=%lu sec, active level=%s", _currentSpeed,
           maxOnTime, ACTIVE_LEVEL == LOW ? "LOW" : "HIGH");
}

void FanActuator::setSpeed(int percent, bool manual) {
  if (percent < 0)
    percent = 0;
  if (percent > 100)
    percent = 100;

  if (manual) {
    LOG_DEBUG(CAT_FAN, "Manual speed change to %d%%", percent);
  }

  _currentSpeed = percent;

  if (_state && !_startingPulseActive) {
    applySpeed(_currentSpeed);
  }
}

int FanActuator::getSpeed() const {
  return _currentSpeed;
}

void FanActuator::update() {
  if (_startingPulseActive) {
    if (millis() - _startingPulseStart >= PWM_STARTING) {
      _startingPulseActive = false;
      applySpeed(_currentSpeed);
      LOG_DEBUG(CAT_FAN, "Start pulse done, speed=%d%%", _currentSpeed);
    }
    return;
  }

  ActuatorBase::update();
}

void FanActuator::onSetPhysical(bool on) {
  if (on) {
    if (_currentSpeed < 100 && _currentSpeed > 0) {
      _startingPulseActive = true;
      _startingPulseStart = millis();
      applySpeed(100);
    } else {
      applySpeed(_currentSpeed);
    }
  } else {
    applySpeed(0);
    _startingPulseActive = false;
  }
}

void FanActuator::applySpeed(int percent) {
  if (percent <= 0) {
    disablePWM();
    digitalWrite(_pin, !ACTIVE_LEVEL);
  } else if (percent >= 100) {
    disablePWM();
    digitalWrite(_pin, ACTIVE_LEVEL);
  } else {
    int pwmValue = percentToPWMValue(percent);
#if ACTIVE_LEVEL == LOW
    pwmValue = 255 - pwmValue;
#endif
    enablePWM();
#ifdef ESP32
    ledcWrite(0, pwmValue);
#elif defined(ESP8266)
    analogWrite(_pin, pwmValue);
#endif
  }
}

void FanActuator::enablePWM() {
  if (_pwmActive)
    return;
#ifdef ESP32
  ledcAttachPin(_pin, 0);
#endif
  _pwmActive = true;
}

void FanActuator::disablePWM() {
  if (!_pwmActive)
    return;
#ifdef ESP32
  ledcDetachPin(_pin);
#elif defined(ESP8266)
  analogWrite(_pin, 1024);
  delayMicroseconds(10);
  pinMode(_pin, OUTPUT);
#endif
  _pwmActive = false;
}

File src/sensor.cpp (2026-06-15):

#include "sensor.h"
#include "logger.h"

#if DEVICE_TYPE == 1 || DEVICE_TYPE == 2

#include "config.h"

// ========== СТАТИЧЕСКИЕ ПЕРЕМЕННЫЕ ==========
static float _currentTemp = 0;
static float _currentHum = 0;
static bool _sensorOk = false;
static unsigned long _lastSensorRead = 0;
static char _sensorError[64] = "";
static float _humRate = 0;

static unsigned long _lastHumTime = 0;
static float _lastHumValue = 0;

static const Config* _cfg = nullptr;  // указатель на активный конфиг

#if SENSOR_TYPE == 1
static Adafruit_AHTX0 _aht;
#elif SENSOR_TYPE == 2
static DHT _dht(SENSOR_PIN, DHT_TYPE);
#endif

// ========== ВСПОМОГАТЕЛЬНЫЕ ФУНКЦИИ ==========
static bool isSensorValueValid(float temp, float hum) {
  if (temp < TEMP_MIN || temp > TEMP_MAX)
    return false;
  if (hum < 0 || hum > 100)
    return false;
  if (temp == 0.0 && hum == 0.0)
    return false;
  return true;
}

// ========== ПУБЛИЧНЫЕ ФУНКЦИИ ==========

void sensor_init(const Config* cfg) {
  _cfg = cfg;

#if SENSOR_TYPE == 1
  Wire.begin(I2C_SDA_PIN, I2C_SCL_PIN);
  _sensorOk = _aht.begin();
  if (_sensorOk) {
    strcpy(_sensorError, "Waiting for first valid reading");
    LOG_DEBUG(CAT_SENSOR, "AHT10 found, waiting for first valid reading...");
    sensors_event_t humidity, temperature;
    if (_aht.getEvent(&humidity, &temperature)) {
      _currentTemp = temperature.temperature;
      _currentHum = humidity.relative_humidity;
      _sensorError[0] = '\0';
      _lastSensorRead = millis();
      LOG_INFO(CAT_SENSOR, "First reading: T=%.2f°C, H=%.2f%%", _currentTemp,
               _currentHum);
    }
  } else {
    strcpy(_sensorError, "AHT10 not found");
    LOG_ERROR(CAT_SENSOR, "AHT10 not found! Sensor will be disabled.");
  }

#elif SENSOR_TYPE == 2
  _dht.begin();
  delay(2000);
  _sensorOk = false;
  strcpy(_sensorError, "Waiting for first valid reading");
  LOG_INFO(CAT_SENSOR, "DHT initialized, waiting for first valid reading...");
#endif

  _humRate = 0;
  _lastHumTime = 0;
  _lastHumValue = 0;
}

bool sensor_update() {
  if (!_cfg)
    return false;

  if (strcmp(_sensorError, "AHT10 not found") == 0) {
    return false;
  }

  if (millis() - _lastSensorRead < _cfg->sensorInterval * 1000UL) {
    return false;
  }
  _lastSensorRead = millis();

  bool readSuccess = false;
  float temp = 0, hum = 0;

#if SENSOR_TYPE == 1
  sensors_event_t humidity, temperature;
  if (_aht.getEvent(&humidity, &temperature)) {
    temp = temperature.temperature;
    hum = humidity.relative_humidity;
    readSuccess = true;
  } else {
    _sensorOk = false;
    strcpy(_sensorError, "AHT10 I2C read failed");
    LOG_ERROR(CAT_SENSOR, "AHT10 read error!");
  }
#elif SENSOR_TYPE == 2
  float t = _dht.readTemperature();
  float h = _dht.readHumidity();
  if (!isnan(t) && !isnan(h)) {
    temp = t;
    hum = h;
    readSuccess = true;
  } else {
    _sensorOk = false;
    strcpy(_sensorError, "DHT read failed (NaN)");
    LOG_ERROR(CAT_SENSOR, "DHT read error!");
  }
#endif

  if (readSuccess) {
    if (isSensorValueValid(temp, hum)) {
      if (_lastHumTime > 0) {
        float dt = (millis() - _lastHumTime) / 1000.0;
        if (dt > 0.1) {
          _humRate = (hum - _lastHumValue) / dt;
          if (_humRate > 5.0)
            _humRate = 5.0;
          if (_humRate < -5.0)
            _humRate = -5.0;
        }
      } else {
        _humRate = 0;
      }

      _lastHumValue = hum;
      _lastHumTime = millis();

      bool changed =
          (fabs(_currentTemp - temp) > 0.05 || fabs(_currentHum - hum) > 0.05);

      _currentTemp = temp;
      _currentHum = hum;
      _sensorOk = true;
      _sensorError[0] = '\0';

      LOG_DEBUG(CAT_SENSOR, "T=%.2f°C, H=%.2f%% (rate=%.2f%%/s)", _currentTemp,
                _currentHum, _humRate);

      return changed;
    } else {
      _sensorOk = false;
      snprintf(_sensorError, sizeof(_sensorError),
               "Out of range (T=%.1f H=%.1f)", temp, hum);
      _humRate = 0;
      LOG_ERROR(CAT_SENSOR, "%s", _sensorError);
      return false;
    }
  } else {
    _humRate = 0;
    return false;
  }
}

float sensor_getTemperature() {
  return _currentTemp;
}

float sensor_getHumidity() {
  return _currentHum;
}

bool sensor_isOk() {
  return _sensorOk;
}

const char* sensor_getError() {
  return _sensorError;
}

float sensor_getHumRate() {
  return _humRate;
}

#endif  // DEVICE_TYPE == 1 || DEVICE_TYPE == 2

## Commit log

2024-01-28 Update main.cpp
    Пример датчика температуры и влажности AHT10
2024-01-28 Update main.cpp
    Предварительная реализация универсального класса Sensor
2024-01-29 Update main.cpp
    прототип
2024-01-29 Update main.cpp
    начало работы с EEPROM
2024-01-30 Update main.cpp
    прототип EEPROM_FEATURE
2024-01-30 Update main.cpp
    Инициализация предварительно
2024-01-30 Update main.cpp
    Прототип (датчик+выключатель)
2024-01-31 Update main.cpp
    Прототип (датчик+выключатель+OTA)
2024-01-31 Update main.cpp
    bugfix: исправлена ошибка в определении факта изменения показаний датчика температуры/влажности
    [main.cpp]
2024-01-31 Delete SensorTemperatureHumidity.h
    Удаление мусора
2024-01-31 Update main.cpp
    Изменение в методах получения показаний датчика температуры/влажности
2024-01-31 ESP8266+ESP32
    SENSOR+RELAY+OTA
2026-05-06 ver 0.1
    first stage commit
    [Fan.kicad_pcb, Fan.kicad_sch]
2026-05-08 some errors fix
    Before logic refactoring
    [config.h, main.cpp]
2026-05-09 bugfix
    -captive 8266
    +mac in wifi/mqtt_id
    [config.h]
2026-05-12 Adaptive fan speed
    Automatic speed adjust for device type 1
    Some bug fixes
    Some refactors
    [config.h, main.cpp, sensor.cpp]
2026-05-13 fan: speed-based adaptive step
    scale adaptive PWM step by rate of humidity change
2026-05-27 prototype v. 1.0
2026-05-31 prototype 1.2
2026-06-01 web refactoring
    ESP32 too
2026-06-01 DEBUG_WIFI_ENABLED bugfix for ESP32
    [main.cpp]
2026-06-01 bugfix LED/DHT pins
2026-06-01 bugfix
    manual mode depend sensor error
    web buttons
    [main.cpp]
2026-06-01 ESP32 OTA bugfix
2026-06-02 prototype 1.3
    remove logging in production mode
2026-06-04 fan adaptive logic fix
2026-06-05 refactor(mqtt): isolate MQTTManager from global config and state
    - MQTTManager.begin() now accepts explicit parameters
    - Removed publishConfig() - initial config published from main.cpp
    - MQTTManager no longer reads config.*, currentTemp, currentHum, fanOn
    - Added state tracking in loop() for all config parameters
    - Fixed misleading 'Connection lost' message on first connect
    - Disabled CORE_DEBUG_LEVEL=5 for cleaner logs
    [main.cpp]
2026-06-05 refactor(web): remove staticConfig, read EEPROM directly for settings page
    - Remove global staticConfig variable (saves 356 bytes RAM)
    - Add config_getSaved() to read config from EEPROM on demand
    - Web config page now reads saved settings via config_getSaved()
    - Web status page continues using current runtime config (global config)
    - Fan restores speed from saved settings using config_getSaved()
    - Remove staticConfig copy from config_write()
2026-06-05 refactor(web): full encapsulation, remove staticConfig
    - Add config_getSaved() to read saved settings from EEPROM on demand
    - Move all status page HTML generation from template to web_buildStatusHtml()
    - Template renderStatusPage() now receives ready-made status HTML string
    - Template renderConfigPage() now receives all data as parameters (savedConfig, currentMode, currentSsid, currentIp)
    - Web no longer depends on mqtt.h, sensor.h, fan.h, switch.h directly
    - Fix duplicate <title> tag in both status and config pages
    - Fan restores speed from EEPROM using config_getSaved() when turned OFF
    Now:
    - /status page shows current runtime co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
2026-06-05 remove async webserver for ESP32
2026-06-06 refactor(config)
    инкапсуляция конфигурации через геттеры/сеттеры
2026-06-06 refactor(sensor): инкапсуляция датчика через геттеры
    - Удалены глобальные переменные currentTemp, currentHum, sensorOk, sensorError, humRate
    - Добавлен API: sensor_getTemperature(), sensor_getHumidity(), sensor_isOk(),
    sensor_getError(), sensor_getHumRate()
    - sensor_read() заменён на sensor_update() с возвратом bool
    - Все модули (fan, main, web) переведены на новый API
2026-06-06 refactor(actuator): объединение fan/switch в единый актуатор
    - Создан ActuatorBase с общей логикой (таймер, maxOnTime)
    - FanActuator наследует ActuatorBase, добавляет ШИМ и адаптацию
    - SwitchActuator наследует ActuatorBase (только вкл/выкл)
    - Инкапсуляция: геттеры/сеттеры для состояния и скорости
    - Удалены старые файлы fan.cpp, fan.h, switch.cpp, switch.h
    Тестирование: MQTT команды работают, таймер включения/выключения работает,
    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
2026-06-07 fix(web): адаптация под новый API актуатора
    В предыдущем коммите (refactor(actuator)) были удалены глобальные функции
    fan_getState(), fan_set(), fan_setOverrideMode(), но web.cpp продолжал их использовать.
    Заменены вызовы:
    - fan_getState() → fan.getState()
    - fan_set() → fan.set(..., true)
    - fan_setOverrideMode() → config_setSensorControlMode() + fan.setAdaptiveMode()
    Теперь проект полностью переведён на новую архитектуру.
2026-06-07 fix(actuator): приведение алгоритмов к заданной логике
    - Добавлен onManualCommandCallback в ActuatorBase
    - Переписан set() — сначала режим, потом состояние
    - Таймер теперь вызывает set(true, true) для переключения режима
    - Убран дублирующий вызов config_setSensorControlMode(false) из web.cpp
    - FanActuator реализует колбэк для установки sensorControlMode=false
    - Добавлены комментарии отладки для web
    [config.h, fan_actuator.cpp]
2026-06-07 fix(fan/sensor)
    Возврат логики управления сенсором
    [fan_actuator.cpp, main.cpp]
2026-06-07 fix (mqtt) Публикация версии
    [config.h, main.cpp]
2026-06-07 refactor(web): удалён DNSServer, унифицирован AP режим
    - Удалён DNSServer для ESP8266
    - Унифицирована инициализация AP: общие обработчики вынесены за #ifdef
    - Добавлен лог запуска сервера в AP режиме
    - Упрощён web_update() до server.handleClient()
2026-06-08 fix (multiple)
    TODO fix:
    [+] Удалить дублирование кода для getResetReason()
    [+] Исправить: для типа 2/3 ошибки в названиях топиков.
    [+] В web нет отображения оставшегося времени и состояния таймеров
    [+] Исправить отсутствие публикации MQTT значений для датчика и выключателя, rssi, версии и др
    [fan_actuator.cpp, main.cpp]
2026-06-08 fix(для maxOnTime,delaySeconds)
    fix: переход в ручной режим отключает Режим управления таймером
    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
    [fan_actuator.cpp, main.cpp]
2026-06-09 led EMERGENCY_STOP
2026-06-09 refactor: вынести WiFi и OTA в отдельные слои
    - Создан wifi_manager.h/cpp — слой управления WiFi (подключение, AP, RSSI, IP)
    - Создан ota.h/cpp — слой обновления прошивки (ElegantOTA)
    - Устранены циклические зависимости: wifi_manager теперь не знает о web
    - Исправлен порядок включения заголовков для корректной компиляции ESP32/ESP8266
    - Убраны дублирования #include и диагностические pragma
    - web_templates.h теперь использует ota_is_available() вместо w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
    [config.h, main.cpp]
2026-06-10 fix (web config)
    - для ESP32 буферизировать вывод для ускорения отображения страницы
    - мелкие правки
    - только конфигурация в режиме AP на /
    [config.h, main.cpp]
2026-06-11 ref (led)
2026-06-11 ref (led and wifi manager)
2026-06-13 upd (remove debug)
    форматирование кода
    блок LED перемещен в начало цикла
    исправлены приоритеты для LED
    устранена задержка в AP режиме - для чистой индикации LED
    [config.h, fan_actuator.cpp]
2026-06-13 fix (add not initialized variables)
    FanActuator::_rampUpActive
    FanActuator::_lastRampUpTime
    MQTTManager::_clientId'
    [fan_actuator.cpp]
2026-06-13 upd (todo mqtt)
    [x] Расширить понимаемые значения для MQTT reset
2026-06-14 fix (remove debug tails)
    [main.cpp]
2026-06-14 upd (ic2)
    кастомные пины для I2C
2026-06-14 clear (led)
    удаление избыточных директив препроцессора для слоя LED
2026-06-14 clear (web)
    Удаление возможности сброса настроек посредством web интерфейса
2026-06-14 clear (wipi power)
    Удалена регулировка мощности сигнала wifi
2026-06-14 clear (web)
    удаление избыточных директив препроцессора для слоя WEB
2026-06-14 fix (OTA)
    clean - remove isOtaAvailable()/ota_set_available()/ota_available
    [main.cpp]
2026-06-14 upd (led)
    Slow blink every second
2026-06-15 Refactor: универсальная архитектура с поддержкой транспортов

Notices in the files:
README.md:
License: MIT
